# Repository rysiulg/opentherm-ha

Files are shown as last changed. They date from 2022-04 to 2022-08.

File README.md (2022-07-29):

Own implementation
Integration opemntherm co gas boiler to homeassistant
Covers in backgroung autodiscovery homeassistant mqtt climate controls also
CO Heat depends on NEWS temperature -it starts only if outside temp is below some value (default 2degC) -this temp is get from mqtt broker as averange NEWS temp.
Control is also available by www ;)
Default temp_NEWS have value 0 and default cutoff_NEWS is 2 so at defult heating is controlled, if from some reason communication is broke to mqqt to get new NEWS sensor than every temp_NEWS_interval_reduction_time_ms (default 30min) temp NEWS is reduced by 5% to finally get tempCutof value to enable heating.
Automode is control by room temp sensor and room temp target, heat mode is based on temperature CO pipe
In mqtt queue are double state value for dhw and double for boiler. eg. ch_state is centrah heat state with state reded from boiler, ch_state_software is software state which tells if we allow heat co. This is used for graphs -I use ch_state to make gradient on graph below Boiler temperature to see when boiler heated co, and flame status tells that boiler works.

Gets from mqtt broker
- temperature of NEWS (north, west south east averange temperature)
- state of working carbon heat co pump works -it disables hest to co

Built in similar interface like webserial, but on same websocket. autoscroll is on when slider is on bottom -in other case autoscroll in terminal is off ;) -it' is also possible to send some commands -i've done in 2 parts one is common for other modules ans other is for local project to be compatible with other projects ;)

Change to AsyncMQTT -by #define switch is possible to back to pubsync MQTT
added also #defined switch to be able on or off some module like arduino ota, influxdb etc.

ToDo:
Add histeresa to Boiler water and mayby for CO..
Add corrections to enable webupdate from bin file -but ota works well and stable for now ;)

Current UI on websockets:




for me it's working only local, remotelly over my VPN ;)

Old UI:


HomeAssistaNT:




Now updated version of http interface:

PLATFORM: Espressif 8266 (4.0.1) > WeMos D1 R2 and mini
HARDWARE: ESP8266 80MHz, 80KB RAM, 4MB Flash
PACKAGES:
 - framework-arduinoespressif8266 @ 3.30002.0 (3.0.2)
 - tool-esptool @ 1.413.0 (4.13)
 - tool-esptoolpy @ 1.30000.201119 (3.0.0)
 - tool-mklittlefs @ 1.203.210628 (2.3)
 - tool-mkspiffs @ 1.200.0 (2.0)
 - toolchain-xtensa @ 2.100300.210717 (10.3.0)
LDF: Library Dependency Finder -> https://bit.ly/configure-pio-ldf
LDF Modes: Finder ~ chain, Compatibility ~ soft
Found 43 compatible libraries
Scanning dependencies...
Dependency Graph
|-- ESPAsyncTCP-esphome @ 1.2.3
|-- ESPAsyncWebServer-esphome @ 2.1.0
|   |-- ESPAsyncTCP-esphome @ 1.2.3
|   |-- Hash @ 1.0
|   |-- ESP8266WiFi @ 1.0
|-- AsyncMqttClient-esphome @ 0.8.6
|   |-- ESPAsyncTCP-esphome @ 1.2.3
|-- ESP_DoubleResetDetector @ 1.3.1
|   |-- EEPROM @ 1.0
|   |-- LittleFS @ 0.1.0
|-- ESP8266 Influxdb @ 3.12.0
|   |-- ESP8266HTTPClient @ 1.2
|   |   |-- ESP8266WiFi @ 1.0
|   |-- ESP8266WiFi @ 1.0
|-- DallasTemperature @ 3.11.0
|   |-- OneWire @ 2.3.7
|-- OneWire @ 2.3.7
|-- OpenTherm Library @ 1.1.3
|-- ESP8266WiFi @ 1.0
|-- LittleFS @ 0.1.0
|-- ArduinoOTA @ 1.0
|   |-- ESP8266WiFi @ 1.0
|   |-- ESP8266mDNS @ 1.2
|   |   |-- ESP8266WiFi @ 1.0
|-- DNSServer @ 1.1.1
|   |-- ESP8266WiFi @ 1.0
|-- ESP8266HTTPClient @ 1.2
|   |-- ESP8266WiFi @ 1.0
|-- ESP8266mDNS @ 1.2
|   |-- ESP8266WiFi @ 1.0
|-- Hash @ 1.0
|-- Ticker @ 1.0
|-- EEPROM @ 1.0
Building in release mode
Compiling .pio\build\d1_mini\src\main.cpp.o
Linking .pio\build\d1_mini\firmware.elf
Retrieving maximum program size .pio\build\d1_mini\firmware.elf
Checking size .pio\build\d1_mini\firmware.elf
Advanced Memory Usage is available via "PlatformIO Home > Project Inspect"
RAM:   [=====     ]  54.7% (used 44840 bytes from 81920 bytes)
Flash: [======    ]  59.7% (used 623681 bytes from 1044464 bytes)

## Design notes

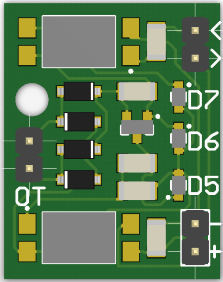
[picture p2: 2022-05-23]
PBA/opentherm_adapter_pcb.png

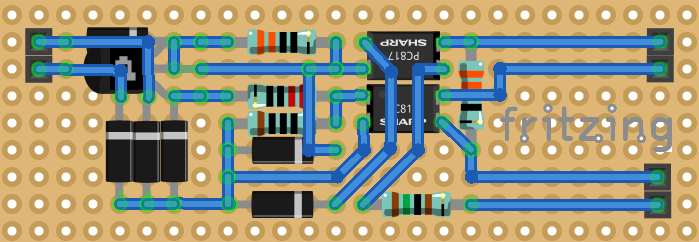
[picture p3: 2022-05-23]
PBA/arduino_opentherm_controller_circuit_board.png

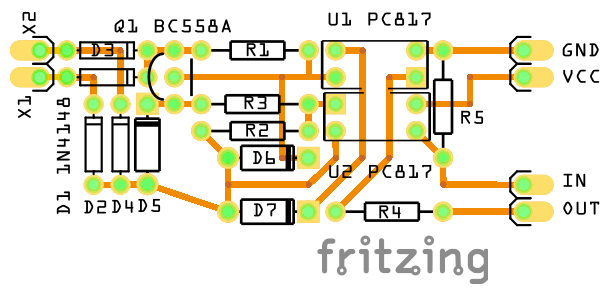
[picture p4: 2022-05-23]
PBA/arduino_opentherm_controller_PCB.png

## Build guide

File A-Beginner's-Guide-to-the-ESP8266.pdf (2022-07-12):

# A Beginner's Guide to the ESP8266

Pieter P, 08-03-2017

Some time ago, I wrote a Beginner's Guide to Arduino that seems to be very popular, so I decided to create a follow-up: A Beginner's Guide to the ESP8266. That's right, a tutorial on how to use the world's most popular $3 Wi-Fi board.

This is going to be a very in-depth tutorial, covering some networking concepts as well. If you're a beginner, and just want to go straight to the more exciting Wi-Fi part, feel free to do so, I included short TL;DR's in the longer, more technical parts.

A short overview of what I'll cover in this article:

1. What is an ESP8266? A short overview of what an ESP8266 is, and what you can do with it
2. Deciding on what board to buy: There's loads of different ESP8266 available these days, finding the one that's best for you can be hard
3. Installing the software: you need to install some software to program the ESP8266, and maybe a USB driver
4. Setting up the hardware: some modules and boards need some external components
5. The ESP8266 as a microcontroller: the ESP8266 can be used as a normal microcontroller, just like an Arduino
6. Network protocols: Before we start using the Wi-Fi capabilities of the ESP8266, I'll teach you some of the network protocols involved
7. Setting up a Wi-Fi connection: That's probably why you're reading this, right?
8. Name resolution: Find the ESP8266 on your local network using mDNS
9. Setting up a simple web server: This enables you to add web pages to the ESP8266, and browse them from your computer or phone
10. Setting up an advanced web server: a more advanced server with a real file system that allows you to upload new files over Wi-Fi
11. OTA - uploading programs over Wi-Fi: You don't have to upload programs over USB, you can use Wi-Fi instead
12. Wirelessly controlling your RGB lighting: Change the color of your LED strips using your phone or computer
13. Getting the time: Connect to a time server using NTP and sync the ESP's clock
14. Monitoring sensors: log the temperature in your living room, save it in flash memory and show it in a fancy graph in your browser
15. Getting email notifications: Turn on a notification light when you've got unread emails
16. Advanced features: use DNS, captive portals, Wi-Fi connector libraries, OSC ...

This guide expects some basic knowledge of microcontrollers like the Arduino. If that's something you're not already familiar with, I'd recommend you to read my Beginner's Guide to Arduino first, it covers a lot of the basics that I won't go into in this article.
I really want to focus on the ESP8266-specific things, like Wi-Fi and other network protocols, the ESP's hardware, software, IoT, etc ...

### What is an ESP8266?

The ESP8266 is a System on a Chip (SoC), manufactured by the Chinese company Espressif. It consists of a Tensilica L106 32-bit micro controller unit (MCU) and a Wi-Fi transceiver. It has 11 GPIO pins* (General Purpose Input/Output pins), and an analog input as well. This means that you can program it like any normal Arduino or other microcontroller. And on top of that, you get Wi-Fi communication, so you can use it to connect to your Wi-Fi network, connect to the Internet, host a web server with real web pages, let your smartphone connect to it, etc ... The possibilities are endless! It's no wonder that this chip has become the most popular IOT device available.

There are many different modules available, standalone modules like the ESP-## series by AI Thinker, or complete development boards like the NodeMCU DevKit or the WeMos D1. Different boards may have different pins broken out, have different Wi-Fi antennas, or a different amount of flash memory on board.

(*) The ESP8266 chip itself has 17 GPIO pins, but 6 of these pins (6-11) are used for communication with the on-board flash memory chip.

### Programming

There are different ways to program the ESP8266, but I'll only cover the method using the Arduino IDE. This is really easy for beginners, and it's a very familiar environment if you've used Arduino boards before.
Just keep in mind that it's not limited to this option: there's also an official SDK available to program it in real C, this is very useful if you want to optimize your code or do some advanced tricks that aren't supported by the Arduino IDE. Another possibility is to flash it with a LUA interpreter, so you can upload and run LUA scripts. Or maybe you're more familiar with Python? Then you should check out the MicroPython firmware to interpret MicroPython scripts. I'm sure there's other languages available as well, so just do a quick Google search and write your code in the language of your choice.

### Requirements

You'll need a couple of things in order to follow this guide:

An ESP8266 board
A computer that can run the Arduino IDE (Windows, Mac or Linux)
A USB-to-Serial converter, it is very important that you use a 3.3V model* A USB cable
A 3.3V power supply or voltage regulator*
A Wi-Fi network to connect to

(*) Your board may already include these. More information can be found in the next chapter.

## Hardware

### Deciding on what board to buy

ESP8266 is just the name of the chip, many companies have designed their own boards that use this chip, so there are many different ESP8266 boards on the market. If you don't know the difference between all these different models, you might have a hard time deciding on what board to buy.

The easiest (and fastest) way to get an ESP8266 board is to buy one from a well-known electronics shop like Adafruit or SparkFun, but if you want it cheap, you should check out Ebay or other sites where you can order them directly from China.

Development boards

Some boards have all kinds of features on-board to help developing ESP8266 hardware and software: for example, a USB to Serial converter for programming, a 3.3V regulator for power, on-board LEDs for debugging, a voltage divider to scale the analog input ...
If you're a beginner, I would definitely recommend a development board. It's easier to get started if you don't have to worry about all these things.

Bare-bones AI Thinker boards

If you want to add an ESP8266 to a small project, or if you want a cheaper* board, you might want to buy a board that doesn't have these features. In that case, you can buy one of the many ESP-## modules developed by AI Thinker. They contain just the ESP8266 and the necessary components to run it.
To program the board, you'll need an external USB-to-Serial converter. With some modules, you get an on-board antenna (PCB or ceramic) and an LED, some boards have just

an antenna connector, or no LEDs at all. They also differ in physical size, and flash memory size. An important thing to notice, is that some boards do not break out all GPIO pins. For example, the ESP-01 only has 2 I/O pins available (apart from the TX and RX pins), while other modules like the ESP-07 or ESP-12 break out all available I/O pins.

(*) The board itself is cheaper, but you'll have to spend more on external parts.

Overview

Here's a table with some of the most popular ESP8266 development boards and their features:

Board | GPIO

3.3V
Vreg

USB-to-Serial

Auto-Reset

Auto-Program

Flash | ADC
range Extra

SparkFun ESP8266
Thing
11 | + | - | + | ±*

512KB
(4Mb)

0-1V

Battery charger, crypto
element, temperature sensor, light sensor

SparkFun ESP8266
Thing - Dev Board
11 | + | + | + | +

512KB
(4Mb)

0-1V

Node MCU | 11 | + | + | + | + | 4MB (32Mb)

0-
3.3V

Adafruit Feather
HUZZAH with
ESP8266
11 | + | + | + | + | 4MB (32Mb) 0-1V | Battery charger

Adafruit HUZZAH
ESP8266 Breakout
11 | + | - | - | - | 4MB (32Mb) 0-1V | 5V-tolerant RX and Reset pins

ESP-##

4 -
11

512KB
(4Mb) –
4MB (32Mb)

0-1V Small and cheap

You can find the full list of ESP-## modules here.

As you can see, both the Node MCU and the Adafruit Feather HUZZAH are solid choices.

(*) When auto-program on the SparkFun ESP8266 Thing is enabled, you can't use the Serial Monitor.

### Getting the hardware ready

There are two main categories of ESP8266 boards: development boards with a USB interface (USB-to-Serial convertor) on-board, and boards without a USB connection.

Development boards with a USB interface

For example: NodeMCU, SparkFun ESP8266 Thing - Dev Board, SparkFun Blynk Board, Adafruit Feather HUZZAH with ESP8266 Wi-Fi ...

These boards will show up in Device manager (Windows) or in lsusb (Linux) as soon as you plug them in. They have a 3.3V regulator on-board, and can be programmed over USB directly, so you don't need any external components to get it working.
The only thing you may need to do, is solder on some headers.

Bare-bones boards and boards without a USB interface

This category has 2 sub-categories: boards with a 3.3V regulator on-board, and boards with just the ESP8266 and a flash memory chip, without 3.3V regulator. If your board doesn't have a 5V to 3.3V regulator, buy one separately. You could use an LM1117-3.3 for example. The on-board 3.3V regulator of most Arduino boards is not powerful enough to power the ESP.

To program the board, you'll need a USB-to-Serial converter. The FTDI FT232RL is quite popular, because it can switch between 5V and 3.3V. It is essential that the USB-to-Serial converter you buy operates at 3.3V. If you buy a 5V model, you will damage the ESP8266.

Connecting the USB-to-Serial converter

1. Connect the ground (GND) of the USB-to-Serial converter to the ground of the ESP8266.
2. Connect the RX-pin of the USB-to-Serial converter to the TXD pin of the ESP8266. (On some boards, it's labelled TX instead of TXD, but it's the same pin.)
3. Connect the TX-pin of the USB-to-Serial converter to the RXD pin of the ESP8266. (On some boards, it's labelled RX instead of RXD, but it's the same pin.)
4. If your ESP8266 board has a DTR pin, connect it to the DTR pin of the USB-to-Serial converter. This enables auto-reset when uploading a sketch, more on that later.

Enabling the chip

If you're using a bare-bone ESP-## board by AI Thinker, you have to add some resistors to turn on the ESP8266, and to select the right boot mode.

1. Enable the chip by connecting the CH_PD (Chip Power Down, sometimes labeled CH_EN or chip enable) pin to VCC through a 10KΩ resistor.
2. Disable SD-card boot by connecting GPIO15 to ground through a 10KΩ resistor.
3. Select normal boot mode by connecting GPIO0 to VCC through a 10KΩ resistor.
4. Prevent random resets by connecting the RST (reset) pin to VCC through a 10KΩ resistor.
5. Make sure you don't have anything connected to GPIO2 (more information in the next chapter).

Adding reset and program buttons

If your ESP8266 board doesn't have a reset button, you could add one by connecting a push button to between the RST pin and ground.

To put the chip into programming mode, you have to pull GPIO0 low during startup. That's why we also need a program button. Because it's possible to use GPIO0 as an output, we can't directly short it to ground, that could damage the chip. To prevent this, connect 470Ω resistor in series with the switch. It's important that this resistance is low enough, otherwise, it will be pulled high by the 10KΩ resistor we added in the previous paragraph.

Connecting the power supply

If the ESP8266 module you have doesn't have a 3.3V voltage regulator on board, you have to add one externally. You could use an LM1117-3.3 for example.

1. Connect the first pin of the regulator to ground.
2. Place a 10µF capacitor between pin 2 (Vout) and ground. Watch the polarity!
3. Place a 10µF capacitor between pin 3 (Vin) and ground.
4. Connect pin 2 to the 3.3V or VCCof the ESP8266.
5. Connect pin 3 to a 5V power source, a USB port, for example.

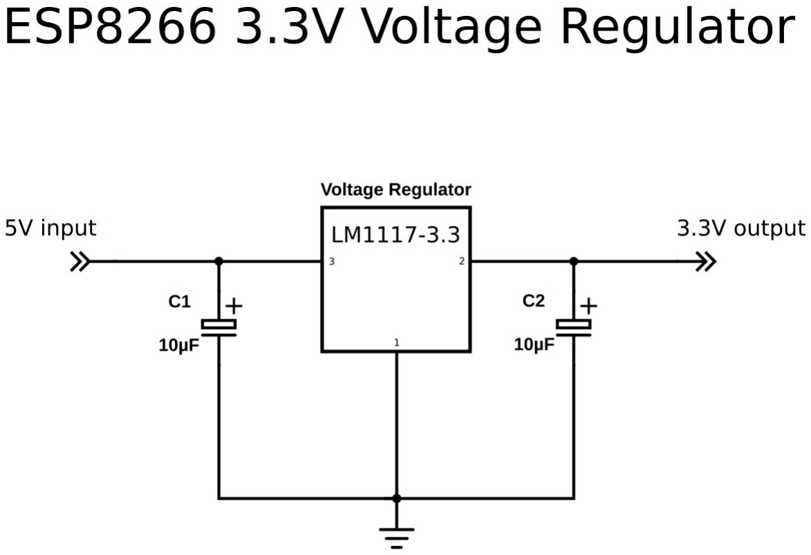
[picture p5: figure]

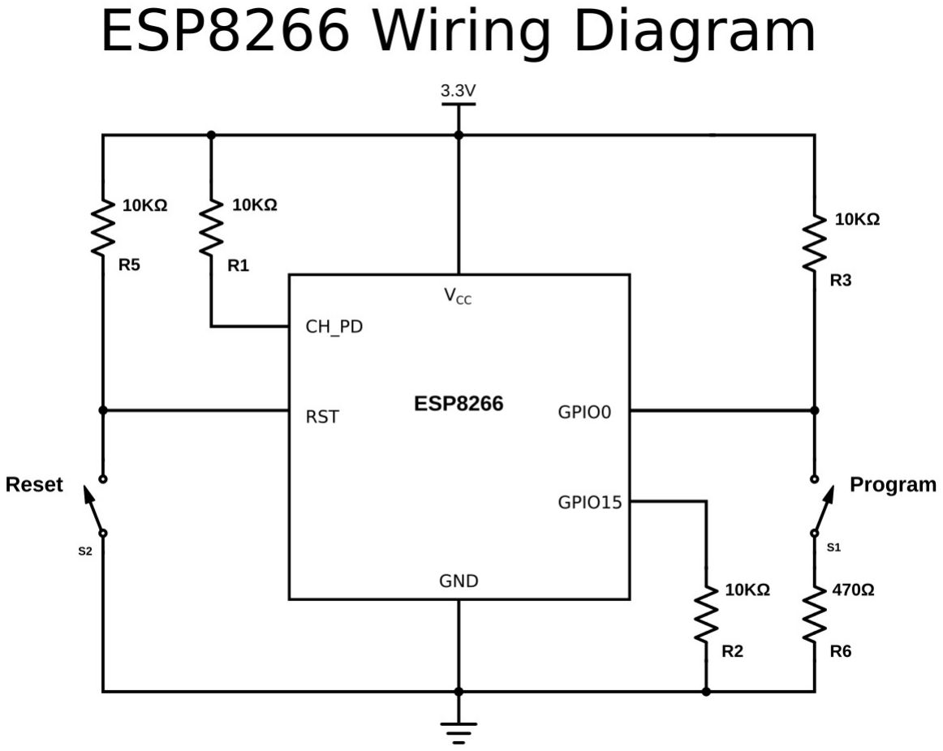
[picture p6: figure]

Before you begin ...

There's a few things you have to look out for when using an ESP8266: The most important thing is that it runs at 3.3V, so if you connect it to a 5V power supply, you'll kill it. Unlike some 3.3V Arduino or Teensy boards, the ESP8266's I/O pins are not 5V tolerant, so if you use a 5V USB-to-Serial converter, or 5V sensors etc. you'll blow it up.
A second thing to keep in mind is that the ESP8266 can only source or sink 12mA per output pin, compared to 20-40mA for most Arduinos.
The ESP8266 has one analog to digital converter, but it has a strange voltage range: 0 - 1V, voltages above 1V might damage the board.

One last thing to keep in mind is that the ESP8266 has to share the system resources and CPU time between your sketch and the Wi-Fi driver. Also, features like PWM, interrupts or I²C are emulated in software, most Arduinos on the other hand, have dedicated hardware parts for these tasks.
For most applications however, this is not too much of an issue.

## Software

### Installation of the required software

The first step is to download and install the Arduino IDE. I explained this in A Beginner's Guide to Arduino. (As of February 7th 2017, the latest stable version of the IDE is 1.8.1.)

To program the ESP8266, you'll need a plugin for the Arduino IDE, it can be downloaded from GitHub manually, but it is easier to just add the URL in the Arduino IDE:

1. Open the Arduino IDE.
2. Go to File > Preferences.
3. Paste the URL http://arduino.esp8266.com/stable/package_esp8266com_index.json into the Additional Board Manager URLs field.
(You can add multiple URLs, separating them with commas.)
4. Go to Tools > Board > Board Manager and search for 'esp8266'. Select the newest version, and click install. (As of February 7th 2017, the latest stable version is 2.3.0.)

You can check out the official install guide here.

Drivers

If you are using a board with the CH340(G) USB-to-Serial chip, like the NodeMCU, you'll probably have to install the USB drivers for it.
They can be found on GitHub.
If you are using a board with the CP2104 USB-to-Serial chip, like the Adafruit Feather HUZZAH board, you'll probably have to install USB drivers as well. You can find them on the Silicon Labs website. Boards with an FTDI chip should work right out of the box, without the need of installing any drivers.

### Python

If you want to use Over The Air updates on Windows, you have to install Python 2.7. You can download it from python.org. During the installation, you have to select the option to add Python to your path. If you don't do this, the Arduino IDE won't be able to find the Python executable.

### Examples

You can find all examples used in this article on my GitHub. Just download it as a .ZIP file, unzip it to a convenient location, and you're good to go!

## The ESP8266 as a microcontroller - Hardware

While the ESP8266 is often used as a ‘dumb’ Serial-to-WiFi bridge, it’s a very powerful microcontroller on its own. In this chapter, we’ll look at the non-Wi-Fi specific functions of the ESP8266.

### Digital I/O

Just like a normal Arduino, the ESP8266 has digital input/output pins (I/O or GPIO, General Purpose Input/Output pins). As the name implies, they can be used as digital inputs to read a digital voltage, or as digital outputs to output either 0V (sink current) or 3.3V (source current).

Voltage and current restrictions

The ESP8266 is a 3.3V microcontroller, so its I/O operates at 3.3V as well. The pins are not 5V tolerant, applying more than 3.6V on any pin will kill the chip.

The maximum current that can be drawn from a single GPIO pin is 12mA.

Usable pins

The ESP8266 has 17 GPIO pins (0-16), however, you can only use 11 of them, because 6 pins (GPIO 6 -
11) are used to connect the flash memory chip. This is the small 8-legged chip right next to the ESP8266. If you try to use one of these pins, you might crash your program.

GPIO 1 and 3 are used as TX and RX of the hardware Serial port (UART), so in most cases, you can’t use them as normal I/O while sending/receiving serial data.

Boot modes

As mentioned in the previous chapter, some I/O pins have a special function during boot: They select 1 of 3 boot modes:

GPIO15 | GPIO0 | GPIO2 | Mode
0V | 0V | 3.3V | Uart Bootloader
0V | 3.3V | 3.3V | Boot sketch (SPI flash)
3.3V | x | x | SDIO mode (not used for Arduino)

Note: you don’t have to add an external pull-up resistor to GPIO2, the internal one is enabled at boot.

We made sure that these conditions are met by adding external resistors in the previous chapter, or the board manufacturer of your board added them for you. This has some implications, however:

GPIO15 is always pulled low, so you can’t use the internal pull-up resistor. You have to keep this in mind when using GPIO15 as an input to read a switch or connect it to a device with an open-collector (or open-drain) output, like I²C.
GPIO0 is pulled high during normal operation, so you can’t use it as a Hi-Z input.
GPIO2 can’t be low at boot, so you can’t connect a switch to it.

Internal pull-up/-down resistors

GPIO 0-15 all have a built-in pull-up resistor, just like in an Arduino. GPIO16 has a built-in pull-down resistor.

PWM

Unlike most Atmel chips (Arduino), the ESP8266 doesn’t support hardware PWM, however, software PWM is supported on all digital pins. The default PWM range is 10-bits @ 1kHz, but this can be changed (up to >14-bit@1kHz).

### Analog input

The ESP8266 has a single analog input, with an input range of 0 - 1.0V. If you supply 3.3V, for example, you will damage the chip. Some boards like the NodeMCU have an on-board resistive voltage divider, to get an easier 0 - 3.3V range. You could also just use a trimpot as a voltage divider.

The ADC (analog to digital converter) has a resolution of 10 bits.

### Communication

Serial

The ESP8266 has two hardware UARTS (Serial ports):
UART0 on pins 1 and 3 (TX0 and RX0 resp.), and UART1 on pins 2 and 8 (TX1 and RX1 resp.), however, GPIO8 is used to connect the flash chip. This means that UART1 can only transmit data.

UART0 also has hardware flow control on pins 15 and 13 (RTS0 and CTS0 resp.). These two pins can also be used as alternative TX0 and RX0 pins.

I²C

The ESP doesn’t have a hardware TWI (Two Wire Interface), but it is implemented in software. This means that you can use pretty much any two digital pins. By default, the I²C library uses pin 4 as SDA and pin 5 as SCL. (The data sheet specifies GPIO2 as SDA and GPIO14 as SCL.) The maximum speed is approximately 450kHz.

SPI

The ESP8266 has one SPI connection available to the user, referred to as HSPI. It uses GPIO14 as CLK, 12 as MISO, 13 as MOSI and 15 as Slave Select (SS). It can be used in both Slave and Master mode (in software).

### GPIO overview

GPIO | Function | State | Restrictions
0 | Boot mode select | 3.3V | No Hi-Z
1 | TX0 | - | Not usable during Serial transmission
2 | Boot mode select TX1 | 3.3V (boot only) | Don’t connect to ground at boot time Sends debug data at boot time
3 | RX0 | - | Not usable during Serial transmission
4 | SDA (I²C) | - | -
5 | SCL (I²C) | - | -
6 - 11 | Flash connection | x | Not usable, and not broken out
12 | MISO (SPI) | - | -
13 | MOSI (SPI) | - | -
14 | SCK (SPI) | - | -
15 | SS (SPI) | 0V | Pull-up resistor not usable
16 | Wake up from sleep | - | No pull-up resistor, but pull-down instead Should be connected to RST to wake up

## The ESP8266 as a microcontroller - Software

Most of the microcontroller functionality of the ESP uses exactly the same syntax as a normal Arduino, making it really easy to get started.

### Digital I/O

Just like with a regular Arduino, you can set the function of a pin using pinMode(pin, mode); where pin is the GPIO number*, and mode can be either INPUT, which is the default, OUTPUT, or INPUT_PULLUP to enable the built-in pull-up resistors for GPIO 0-15. To enable the pull-down resistor for GPIO16, you have to use
INPUT_PULLDOWN_16.

(*) NodeMCU uses a different pin mapping, read more here. To address a NodeMCU pin, e.g. pin 5, use
D5: for instance: pinMode(D5, OUTPUT);

To set an output pin high (3.3V) or low (0V), use digitalWrite(pin, value); where pin is the digital pin, and value either 1 or 0 (or HIGH and LOW).

To read an input, use digitalRead(pin);

To enable PWM on a certain pin, use analogWrite(pin, value); where pin is the digital pin, and value a number between 0 and 1023.

You can change the range (bit depth) of the PWM output by using analogWriteRange(new_range);

The frequency can be changed by using analogWriteFreq(new_frequency);. new_frequency should be between 100 and 1000Hz.

### Analog input

Just like on an Arduino, you can use analogRead(A0) to get the analog voltage on the analog input. (0 = 0V, 1023 = 1.0V).

The ESP can also use the ADC to measure the supply voltage (VCC). To do this, include ADC_MODE(ADC_VCC); at the top of your sketch, and use ESP.getVcc(); to actually get the voltage.
If you use it to read the supply voltage, you can’t connect anything else to the analog pin.

### Communication

Serial communication

To use UART0 (TX = GPIO1, RX = GPIO3), you can use the Serial object, just like on an Arduino:
Serial.begin(baud).

To use the alternative pins (TX = GPIO15, RX = GPIO13), use Serial.swap() after Serial.begin.

To use UART1 (TX = GPIO2), use the Serial1 object.

All Arduino Stream functions, like read, write, print, println, ... are supported as well.

I²C and SPI

You can just use the default Arduino library syntax, like you normally would.

### Sharing CPU time with the RF part

One thing to keep in mind while writing programs for the ESP8266 is that your sketch has to share resources (CPU time and memory) with the Wi-Fi- and TCP-stacks (the software that runs in the background and handles all Wi-Fi and IP connections).
If your code takes too long to execute, and don’t let the TCP stacks do their thing, it might crash, or you could lose data. It’s best to keep the execution time of you loop under a couple of hundreds of milliseconds.

Every time the main loop is repeated, your sketch yields to the Wi-Fi and TCP to handle all Wi-Fi and TCP requests.

If your loop takes longer than this, you will have to explicitly give CPU time to the Wi-Fi/TCP stacks, by using including delay(0); or yield();. If you don’t, network communication won’t work as expected, and if it’s longer than 3 seconds, the soft WDT (Watch Dog Timer) will reset the ESP. If the soft WDT is disabled, after a little over 8 seconds, the hardware WDT will reset the chip.

From a microcontroller’s perspective however, 3 seconds is a very long time (240 million clockcycles), so unless you do some extremely heavy number crunching, or sending extremely long strings over Serial, you won’t be affected by this. Just keep in mind that you add the yield(); inside your for or while loops that could take longer than, say 100ms.

### Sources

This is where I got most of my information to writ this article, there’s some more details on the GitHub pages, if you’re into some more advanced stuff, like EEPROM or deep sleep etc.

https://github.com/esp8266/Arduino/issues/2942https://github.com/esp8266/Arduino/pull/2533/fileshttps://github.com/esp8266/Arduino/blob/master/doc/libraries.mdhttps: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

## Wi-Fi

Using the ESP8266 as a simple microcontroller is great, but the reason why most people use it, is its Wi-Fi capabilities. In this chapter, we'll dive into the wonderful world of network protocols, like Wi-Fi, TCP, UDP, HTTP, DNS ... All these acronyms might intimidate you, but I'll try my best to explain them step-by-step and in an easy way.

Some paragraphs are in italic. These provide some extra information, but are not critical to understanding the ESP's Wi-Fi functions, so don't get frustrated if there are things you don't understand.

It's really hard to give a clear explanation, without over-complicating things and while keeping it short enough as well. If you've got any feedback or remarks, be sure to leave a comment to help improve this article. Thanks!

### The TCP/IP stack

The system most people refer to as 'The Internet' isn't just one protocol: it's an entire stack of layers of protocols, often referred to as the TCP/IP stack. We'll go over these different layers, because we need to understand how our ESP8266 communicates with other devices on the network.

Layer | Protocols
Application | HTTP, FTP, mDNS, WebSocket, OSC ...
Transport | TCP, UDP
Internet | IP
Link | Ethernet, Wi-Fi ...

### The Link layer

The link layer contains the physical link between two devices, an Ethernet cable, for example, or a Wi-Fi connection. This is the layer that is closest to the hardware.
To connect an ESP8266 to the network, you have to create a Wi-Fi link. This can happen in two different ways:
1. The ESP8266 connects to a wireless access point (WAP or simply AP). The AP can be built-in to your modem or router, for example.
In this configuration, the ESP acts like a wireless station.
2. The ESP8266 acts as an access point and wireless stations can connect to it. These stations could be your laptop, a smartphone, or even another ESP in station mode.

Once the Wi-Fi link is established, the ESP8266 is part of a local area network (LAN). All devices on a LAN can communicate with each other.
Most of the time, the AP is connected to a physical Ethernet network as well, this means that the ESP8266 can also communicate with devices that are connected to the AP (modem/router) via a wired Ethernet connection (desktop computers, gaming consoles and set-top boxes, for instance).
If the ESP8266 is in access point mode, it can communicate with any station that is connected to it, and two stations (e.g. a laptop and a smartphone) can also communicate with each other.

The ESP can be used in AP-only, station-only, or AP+station mode.

TL;DR

The link layer is the physical link between devices: in the case of the ESP8266, this is a WiFi connection. The ESP can act as a station and connect to an access point, or act as an access point and let other devices connect to it.

### The Internet or Network layer

Although the devices are now physically connected (either through actual wires (Ethernet) or through radio waves (Wi-Fi)), they can't actually talk to each other yet, because they have no way of knowing where to send the message to.
That's where the Internet Protocol (IP) comes in. Every device on the network has a personal IP address. The DHCP server (Dynamic Host Configuration Protocol Server) makes sure that these addresses are unique.

This means that you can now send a message to a specific address.

There are two versions of the Internet Protocol: IPv4 and IPv6. IPv6 is an improved version of IPv4 and has much more addresses than IPv4 (because there are much more devices than available IPv4 addresses). In this article, we'll only talk about IPv4 addresses, since most LANs still use them.

The IP address consists of 4 numbers, for example 192.168.1.5 is a valid IPv4 address. It actually consists of two parts: the first part is 192.168.1, this is the address of the local network. The last digit, 5 in this case, is specific to the device.

By using IP addresses, we can find the ESP8266 on the network, and send messages to it. The ESP can also find our computer or our phone, if it knows their respective IP addresses.

Sub-net mask (optional)

This subdivision of the IP address is determined by the sub-net mask, often written as 255.255.255.0. You can see that it consists of four numbers, just like the IP address. If a part of the sub-net mask is 255, it means that the corresponding part of the IP address is part of the network address, if it's 0, the corresponding IP part is part of the address of the specific address. A different notation to "IP: 192.168.1.5, sub-net mask: 255.255.255.0" would be "192.168.1.5/24", because the binary representation of the sub-net mask is 11111111.11111111.11111111.00000000, and it has 24 ones. If you want to know more about sub-nets, I'd recommend you to read the Wikipedia article.
(A quick tip to help you remember: it's called the sub-net mask, because if you perform a bitwise AND operation on the IP address and the sub-net mask (i.e. use the sub-net mask as a mask for the IP address), you get the address of the sub-net.)

MAC addresses and ARP (optional)

It is actually impossible to send packets directly to another machine using only the IP address. To send a packet to a specific device on the LAN (Wi-Fi or Ethernet), you have to know its MAC-address. The MAC address is a unique number that is unique for every network device, and it never changes, it's hardwired in the network chip. This means that every ESP8266, every network card, every smartphone ... ever made, has a different MAC address.
So before the ESP can send a packet to your smartphone for example, it has to know its MAC address. It doesn't know this yet, the ESP only knows the IP address of the smartphone, say 192.168.1.6. To do this, the ESP sends a broadcast message (i.e. a message addressed to all devices on the LAN) saying "I'm looking for the MAC address of the device with the IP address 192.168.1.6". The ESP also includes its own IP and MAC address with the message. When the smartphone receives this broadcast message, it recognizes its own IP address, and responds to the ESP by sending its own MAC address. Now the ESP and the phone both know each other's IP and MAC addresses, and they can communicate using IP addresses. This method is called the Addres Resolution Protocol, or ARP.

What about the Internet?

As you might have noticed, I only talked about the local area network, these are the computers in your own house. So how can the ESP8266 communicate with the Internet, you may ask? Well, there's a lot of network infrastructure involved in 'The Internet', and they all obey the IP rules, to make sure most of your packets arrive at there destination. It's not that simple of course, there's a lot of things going on, like routing and Network Address Translation (NAT), but that falls outside the scope of this article, and it's not really something most people have to worry about.

TL;DR

The Internet layer uses IP addresses in order to know where it should send the data. This means that two devices can now send packets of data to each other, even over the Internet.

### The Transport layer

The different devices in the network do their best to deliver these IP packets to the addressee, however, it's not uncommon for a packet to get lost, so it will never arrive. Or the packet might get corrupted on the way: the data is no longer correct. IP also can't guarantee that the packets arrive in the same order they were sent in.
This means that we can't reliably send messages yet by only using the link and the Internet layer, since we can never know when and whether a packet will arrive, or know for certain that a received packet is correct.

We need a third layer on top of the Internet layer: the Transport layer.

There are mainly two protocols that make up this third layer: the Transmission Control Protocol (TCP) and the User Datagram Protocol (UDP).

TCP makes sure that all packets are received, that the packets are in order, and that corrupted packets are re-sent. This means that it can be used for communication between multiple applications, without having to worry about data integrity or packet loss. This is why it's used for things like downloading webpages, sending email, uploading files etc.
UDP on the other hand, doesn't guarantee that every packet reaches its destination, it does check for errors however, but when it finds one, it just destroys the packet, without re-sending it. This means that it's not as reliable as TCP, but it's faster, and has a much lower latency, because it doesn't require an open connection to send messages, like TCP does. That's why it's used in voice and video chats, and for example in online games.

If you want to know more about the differences between TCP and UDP, check out this video.

TL;DR

The IP protocol is not reliable, and has no error checking. TCP solves this by re-sending lost or corrupt packages, and orders packets that are received in the wrong order. UDP also checks for corrupt packages, but doesn't re-send them, so it has less latency than TCP.

### The Application layer

We now have reliable communication using TCP, but there's still one problem. Think of it this way: you are sending a letter, and TCP guarantees that it will arrive at its destination, but if the receiver doesn't understand the language it's written in, he won't know what to do with it.
In other words, we need a fourth layer of protocols, for two programs to be able to communicate with each other.
There's lots of different protocols out there, but we'll mostly focus on the protocols for web servers and browsers.

HyperText Transfer Protocol

The HyperText Transfer Protocol, or HTTP, is the protocol (cfr. language) that is used by both web servers and web clients in order to communicate. It uses text to perform send requests and responses from the client to the server and back again.
For example, when you type http://www.google.com into the address bar of a web browser (client), it will send an HTTP GET request to the Google web server. The server understands this HTTP request, and will send the Google webpage as a response. Or when you upload an image to Instagram, your browser sends an HTTP POST request with your selfie attached to the Instagram server. The server understands the request, saves the image and adds it into the database, sends the URL of the new image back to your browser, and the browser will add the image on the webpage.
As you can see, neither the client nor the server has to worry about the integrity of the messages they send, and they know that the recipient understands their language, and that it will know what to do with a certain HTTP request.
Most modern sites use a secure version of HTTP, called HTTPS. This secure connection encrypts the data, for security reasons. (You don't want anyone reading the packets from your mail server, or the packets you sent to your bank, for instance.)

WebSocket

HTTP is great for things like downloading webpages, uploading photos etc. but it's quite slow: every time you send an HTTP request, you have to start a new TCP connection to the server, then send your request, wait for the server to respond, and download the response. Wouldn't it be great if we didn't have to open a new connection every time we want to send some data, and if we could send and receive data at the same time at any moment we'd like? That's where WebSocket comes to the rescue: you can keep the TCP connection with the server open at all times, you get perfect TCP reliability, and it's pretty fast.

Open Sound Control

HTTP and WebSocket both use TCP connections. What if you want lower latency? Well, Open Sound Control, or OSC, uses UDP to send small pieces of data, like ints, floats, short text etc ... with very low latency. It was originally designed for controlling low latency audio applications, but it's a very flexible protocol, so it's often used for low-latency tasks other than audio control.

Domain Name System

As mentioned before, you can only send a message to another computer if you know its IP address. But when you browse the Internet, you only know a website's domain name (e.g. www.google.com). Your computer uses the Domain Name System to translate this domain name to the right IP address. More on this later.

### Sources

https://en.wikipedia.org/wiki/Internet_protocol_suitehttps://en.wikipedia.org/wiki/Port_(computer_networking) https://en.wikipedia.org/wiki/Transmission_Control_Protocolhttps://en.wikipedia.org/wiki/Internet_Protocolhttps://en.wikipedia.org/wiki/User_Datagram_Protocol

## Uploading sketches to the ESP8266

The upload procedure for ESP8266 boards is a little different from the normal Arduino procedure. Most Arduinos will automatically reset when a new program is being uploaded, and will automatically enter programming mode.
On some ESP boards you have to manually enter programming mode, and on the bare-bones modules, you even have to reset them manually.
However, there are some simple circuits you can use to get automatic uploads.

### Auto-reset

This only applies to boards without an on-board USB-to-Serial converter.

If the USB-to-Serial converter you're using has a DTR flow control line, you can automate the reset signal. When sending data to the ESP, the DTR line goes low, and stays low for some time. To reset the ESP, we need a low pulse on the RST pin. The problem is that the DTR pin stays low. To solve this, we're going to build a crude edge detector circuit, using a capacitor. Take a look at the following schematic:

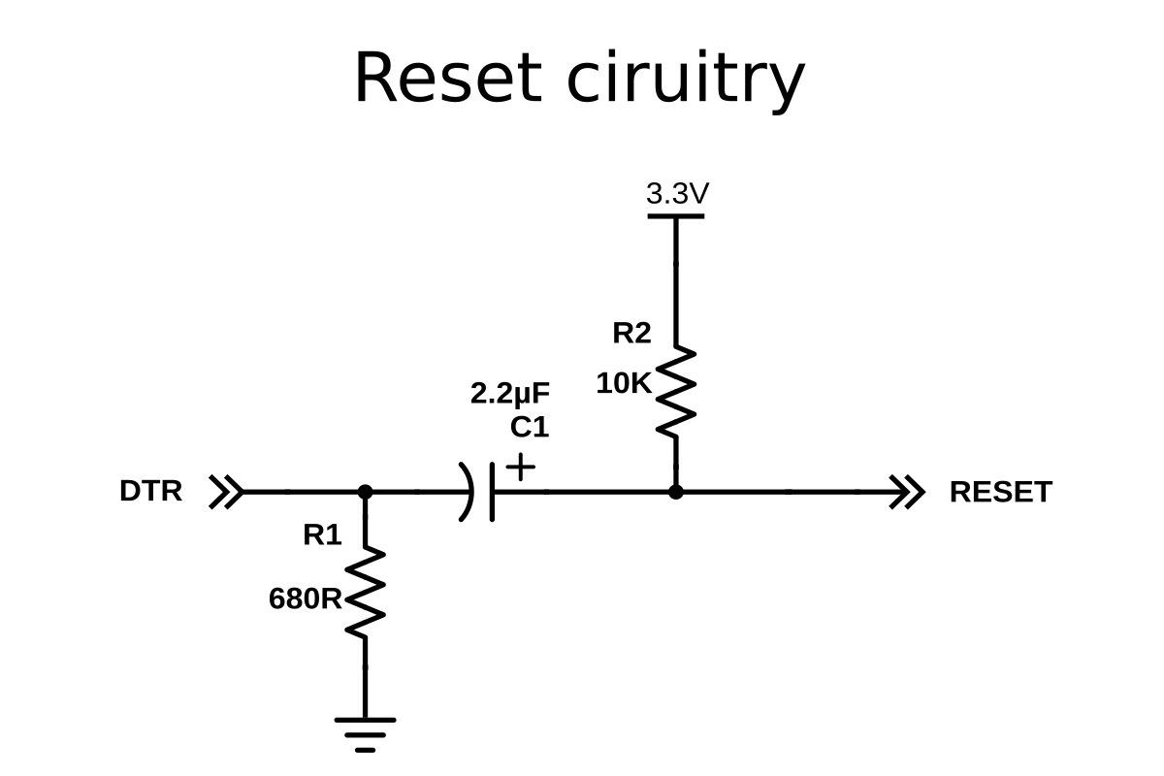
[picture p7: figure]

You might recognize that this is basically a low-cut filter. In normal conditions, DTR is high (3.3V), and the reset line is also high, because of the pull-up resistor R2. This means that the voltage across the capacitor is 0V. When DTR suddenly drops (to 0V), the voltage across the capacitor is still 0V, meaning that the reset line will be at 0V + 0V = 0V, and a reset is triggered.

However, C1 immediately starts charging through R2, and reaches 3.3V. At this point, DTR is still at 0V, meaning that there's now 3.3V across the capacitor. When DTR rises again, the reset line will be at 3.3V

+ 3.3V = 6.6V, and then immediately starts to discharge through R2, finally reaching 3.3V again, with 0V across C1.
This is a problem: 6.6V can damage the ESP, so we have to find a way to get rid of the positive peak.

One glance at this MATLAB simulation shows us the problem even better:

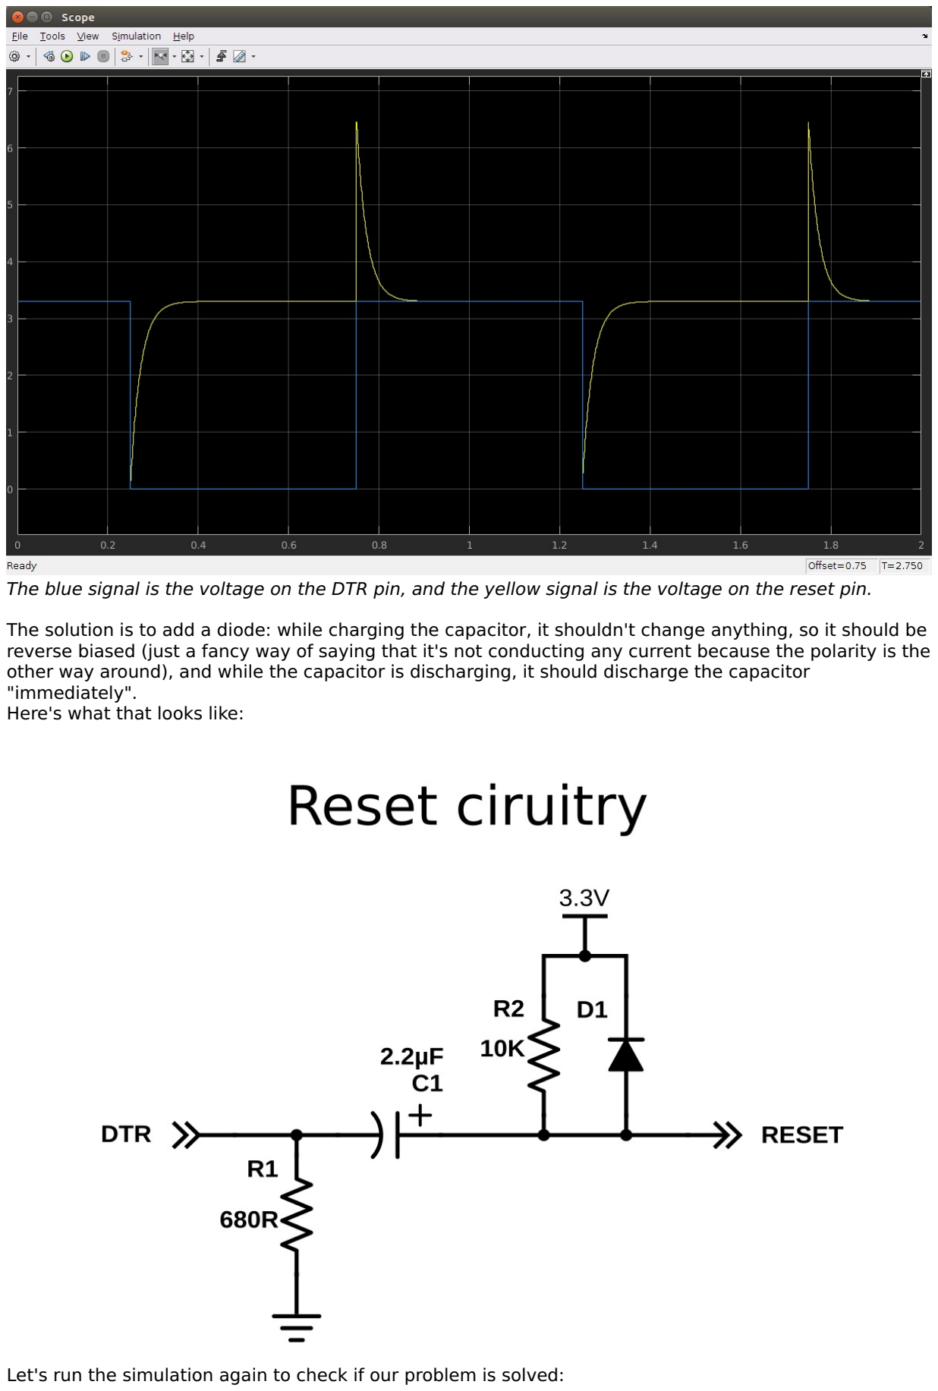
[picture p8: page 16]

The blue signal is the voltage on the DTR pin, and the yellow signal is the voltage on the reset pin.

The solution is to add a diode: while charging the capacitor, it shouldn't change anything, so it should be reverse biased (just a fancy way of saying that it's not conducting any current because the polarity is the other way around), and while the capacitor is discharging, it should discharge the capacitor "immediately".
Here's what that looks like:

Let's run the simulation again to check if our problem is solved:

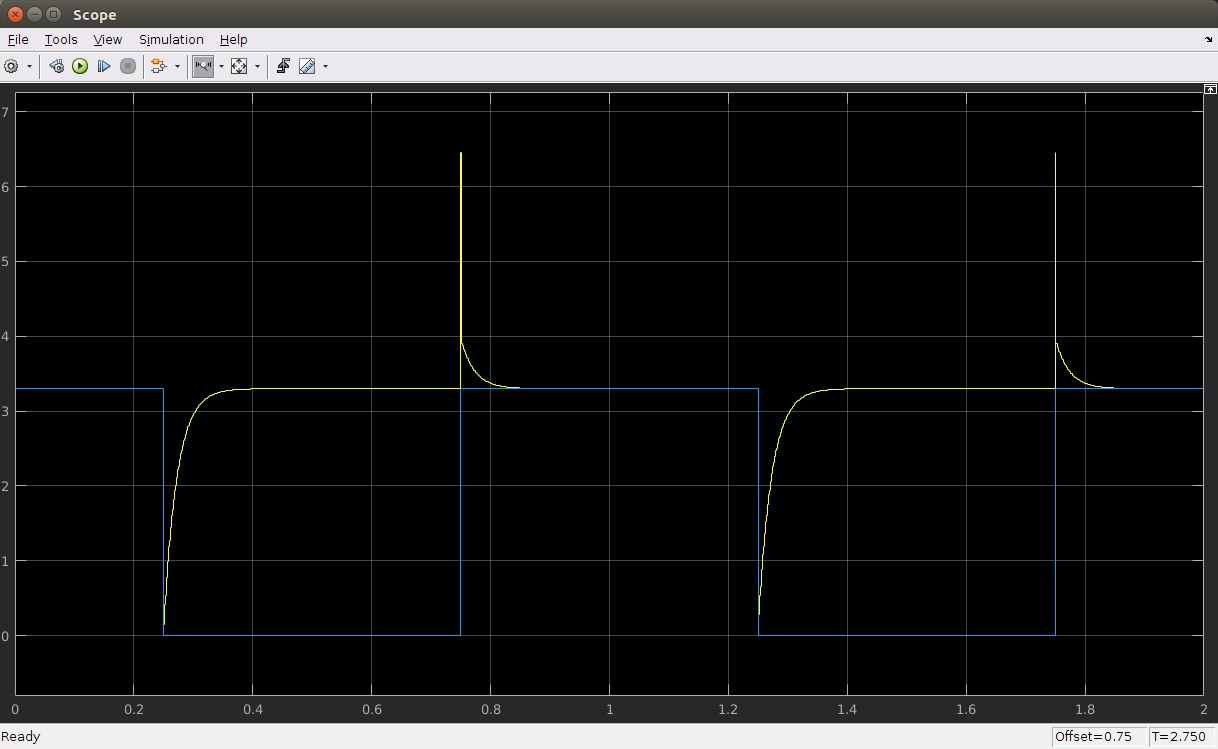
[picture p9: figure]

As you can see, the 6.6V peak is now very narrow, just like we wanted. It's impossible to discharge the capacitor instantly, that would require a capacitor and a diode with 0Ω of series resistance, and an infinite current, which is impossible, obviously. There's also a smaller but relatively wide peak of approximately 3.9V. This is because a diode only conducts when the voltage across it is higher than ~600mV. This means that the last 0.6V that's left in the capacitor (from 3.9 to 3.3V) will still be discharged through R2 only.
Nevertheless, the voltage peak is much lower and narrower than without the diode, and it's safe to connect to the ESP8266.

This exact circuit is also used in the Arduino Uno, for example.

Note: if you followed the instructions in the hardware step correctly, you should already have added R2 to your ESP.

How to use Auto-reset

To use this auto-reset circuit, connect it to the DTR line of your USB-to-Serial converter, and to the reset line of the ESP, as shown in the diagram. Then click compile (just because the first compilation can take quite some time). Go to Tools > Reset and select 'ck'. When it's done compiling, hold down the program button we added in the hardware step, and click upload. Wait for it to say "Uploading..." and then release the program button.

### Auto-reset and Auto-program

This only applies to boards without an on-board USB-to-Serial converter.

The method above still requires you to press a button to upload a new sketch. If your USB-to-Serial converter has a RTS line as well as a DTR line, you can automate the entire process.

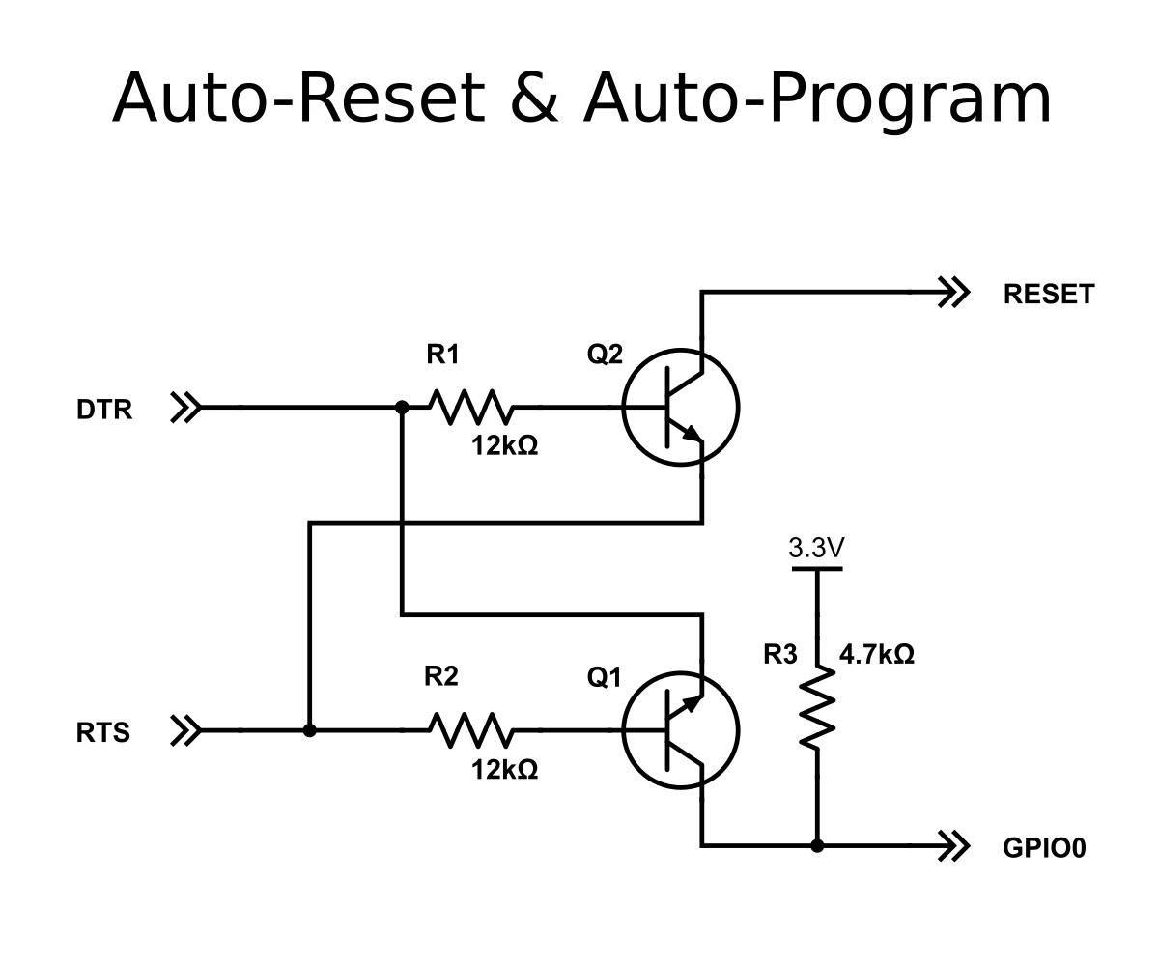
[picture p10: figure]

You may find out that the 4.7kΩ resistor doesn't work for you. In that case, try some other value, like 10kΩ, for example.

This method was first used in the NodeMCU, so go to Tools > Reset Method, and select "nodemcu". This will drive the DTR&RTS pins high and low in the right sequence to get it in programming mode before uploading.

This is by far the best method, but the problem is that you need access to both the RTS and DTR pins, while most USB-to-Serial adapters break out only one of the two.

### Manual reset and manual program

This only applies to boards without an on-board USB-to-Serial converter.

If you don't have a USB-to-Serial converter with DTR and RTS lines, you could also just use the reset and program buttons we added in the hardware chapter. To get the ESP in program mode, GPIO0 must be low while booting:

1. press and hold the reset button
2. press and hold the program button
3. release the reset button, the ESP will boot in program mode
4. release the program button
5. upload the sketch

If you want to get out of program mode without uploading, just press reset (without pressing the program button).

### Board options

If your specific board is in the Tools > Board list (e.g. NodeMCU, SparkFun and Adafruit boards), you can just select it, and you will get the right settings. When your board isn't in the list, you'll have to select a Generic ESP8266. In that case there's lots of new options in the Tools menu of the Arduino IDE, so let's go over them and pick the right settings.

Flash Mode

Like I said before, the ESP8266 uses an external flash chip for storage. You can communicate with this chip over 2 datalines (DIO), or over all 4 datalines (QIO). Using 4 lines is two times faster than 2 lines, so in most cases, you should choose QIO. (If you're doing some advanced stuff and you need 2 more GPIO pins, you could use 2 lines instead of 4, and use the 2 lines as I/O. Most modules don't give you access to these pins, though. )

Flash Size

Different boards/modules have different sizes of flash chips on board. There are boards with 512kB, 1MB, 2MB and 4MB of flash. To know how much flash your board has, you can try the Examples > ESP8266 > CheckFlashConfig to see if your flash setting is correct, or you can check the specifications of your specific board online.
You can also select the SPIFFS (SPI Flash File System) size. The SPIFFS partition is a small file system to store files. If you're not using it, you can select the minimum. Later on in the article, we'll use SPIFFS, and I'll remind you to select a larger SPIFFS size, but for now, it doesn't really matter.

Debug port

There's a load of things going on when the ESP is running: Things like Wi-Fi connections, TCP connections, DNS lookups ... you name it. All these small tasks produce a whole lot of debug output to help you troubleshoot. However, in a normal situation, where your program is behaving as expected, you don't need all those debug messages to flood the Serial Monitor, so you can just turn them off by selecting 'Disabled'.
If you do wish to receive debug messages, you can select the port to send them to. (Serial on pins 1 and 3, or Serial1 on pin 2)

Debug level

This allows you to choose what kind of debug messages you want to show.

Reset Method

As mentioned in the paragraphs above, there are different methods for auto-reset and auto-program. If you're using the first method (using the edge detector), you should use 'ck', if you use the two-transistor circuit, select 'nodemcu'.

Flash Frequency

If you need some extra memory speed, you could change the flash frequency from 40MHz to 80MHz. This is the clock frequency of the SPI/SDIO link.

CPU Frequency

If you need some extra CPU performance, you can double the clock speed from 80MHz to 160MHz. It's actually an overclock, but I've never had any issues or instability.

Upload Speed

The baud rate for uploading to the ESP. The default is 115200 baud, but you can go higher (if you're changing your sketch a lot, it might be too slow). 921600 baud works most of the time, but you may get an error sometimes, if that's the case, switching back to 115200 will probably solve all problems.

## Establishing a Wi-Fi connection

Like I mentioned in the previous chapter, the ESP8266 can operate in three different modes: Wi-Fi station, Wi-Fi access point, and both at the same time. We'll start by looking at the configuration of a Wi-Fi station.

### Station mode

Connecting to one specific network

#include <ESP8266WiFi.h> | // Include the Wi-Fi library

const char* ssid | = "SSID"; | // The SSID (name) of the Wi-Fi network you want to connect to
const char* password = "PASSWORD"; | // The password of the Wi-Fi network

void setup() {
Serial.begin(115200); | // Start the Serial communication to send messages to the computer
delay(10);
Serial.println('\n');
WiFi.begin(ssid, password); | // Connect to the network
Serial.print("Connecting to ");
Serial.print(ssid); Serial.println(" ...");

int i = 0;
while (WiFi.status() != WL_CONNECTED) { // Wait for the Wi-Fi to connect delay(1000);
Serial.print(++i); Serial.print(' ');
}

Serial.println('\n');
Serial.println("Connection established!");
Serial.print("IP address:\t");
Serial.println(WiFi.localIP()); | // Send the IP address of the ESP8266 to the computer
}

void loop() { }

The code to connect to a wireless access point is relatively straightforward: enter the SSID and the password of the network you want to connect to, and call the WiFi.begin function. Then wait for the connection to complete, et voilà, your ESP8266 is now connected to your Local Area Network.

Don't believe me? I'll prove it to you: open the Serial monitor (CTRL+SHIFT+M) and upload the sketch. You should see something like this:

Connecting to SSID ...
1 2 3 4 5 6 ...

Connection established!
IP address: 192.168.1.3

Now go to your computer and open up a terminal: On Windows, search for "Command Prompt", on Mac or Linux, search for "Terminal". You could also use the shortcuts: on Windows, hit + R, type "cmd" and hit enter, on Linux, use CTRL+ALT+T .

Next, type ping , and then the IP address you received in the Serial monitor. If you're on Mac or Linux, use CTRL+C to stop it after a couple of lines. The output should look something like this:

user@computername:~$ ping 192.168.1.3
PING 192.168.1.3 (192.168.1.3) 56(84) bytes of data.
64 bytes from 192.168.1.3: icmp_seq=1 ttl=128 time=6.38 ms
64 bytes from 192.168.1.3: icmp_seq=2 ttl=128 time=45.2 ms 64 bytes from 192.168.1.3: icmp_seq=3 ttl=128 time=69.1 ms 64 bytes from 192.168.1.3: icmp_seq=4 ttl=128 time=94.0 ms 64 bytes from 192.168.1.3: icmp_seq=5 ttl=128 time=20.5 ms 64 bytes from 192.168.1.3: icmp_seq=6 ttl=128 time=7.37 ms
^C
--- 192.168.1.3 ping statistics ---
6 packets transmitted, 6 received, 0% packet loss, time 5003ms
rtt min/avg/max/mdev = 6.384/40.463/94.047/32.588 ms

The ping command sends small packets to the IP address of the ESP8266. When the ESP receives such a packet, it sends it back to the sender. Ping is part of the second layer of the TCP/IP stack, the Internet layer. It relies on both the Data Link layer (Wi-Fi) and the Internet Protocol*.
You can see that in the example above, we sent 6 packets to the ESP, and we also received 6 response (echo) packets. This tells us that the Data Link, the Wi-Fi connection, and the Internet Protocol are working correctly.

We now know that the ESP can successfully communicate with other devices on the network, and if your local network is online (if it is connected to the Internet via your modem), the ESP can also communicate with any device on the web !

Ping is a great tool to check if the ESP (or any device, really) is still connected to the network, and if it's still working fine.
One drawback is that IP addresses can change over time, but that's a problem we'll address in one of the following chapters ...

(*) I'm simplifying things a bit here. Actually, ping is part of the Internet Control Message Protocol (ICMP), that's also part of the second layer, just like the Internet Protocol. Don't worry too much about it, just remember that if you can send ping packets to a device, you can also send IP packets.

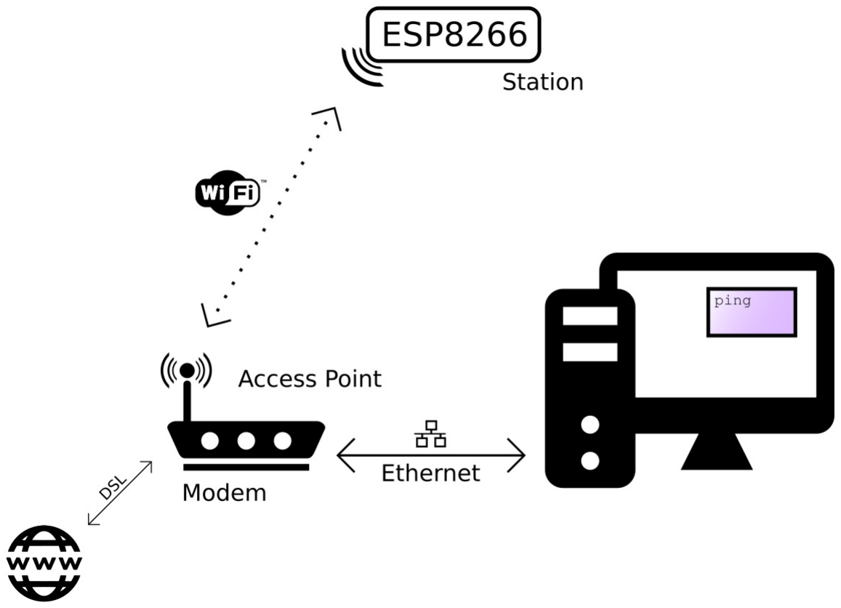
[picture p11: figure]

The device with the antenna serves many different purposes:

Access point: Other Wi-Fi devices can connect to it, to be part of the local network.
Router: It routes IP packets to the right sub-nets so that they will arrive at their destination. E.g. if the computer sends a message that is meant for the ESP over the Ethernet sub-net, the router will send the packet to the Wi-Fi sub-net, because it knows that's where the ESP is. Modem: if the router can't find the addressee on the local network, the packet will be passed on to

the integrated modem, and it will be sent to the Internet Service Provider over a DSL line, heading for the Internet, where lots of other routers will try to get the packet to the right destination.

But in reality, you don't have to worry too much about it, because it's all done for you, in a fraction of a second without you even noticing it!

Automatically connect to the strongest network

The sketch above might be enough for your specific application, but if you need to be able to connect to multiple Wi-Fi networks, for example the Wi-Fi at home and the Wi-Fi at the office, it won't work.
To solve this problem, we'll use the Wi-Fi-Multi library: You can add as many networks as you like, and it automatically connects to the one with the strongest signal.

#include <ESP8266WiFi.h> | // Include the Wi-Fi library

#include <ESP8266WiFiMulti.h> | // Include the Wi-Fi-Multi library

ESP8266WiFiMulti wifiMulti; | // Create an instance of the ESP8266WiFiMulti class, called 'wifiMulti'

void setup() {
Serial.begin(115200); | // Start the Serial communication to send messages to the computer
delay(10);
Serial.println('\n');

wifiMulti.addAP("ssid_from_AP_1", "your_password_for_AP_1"); // add Wi-Fi networks you want to connect to
wifiMulti.addAP("ssid_from_AP_2", "your_password_for_AP_2");
wifiMulti.addAP("ssid_from_AP_3", "your_password_for_AP_3");

Serial.println("Connecting ...");
int i = 0;
while (wifiMulti.run() != WL_CONNECTED) { // Wait for the Wi-Fi to connect: scan for Wi-Fi networks, and connect to the strongest of the networks above
delay(1000);
Serial.print('.');
}
Serial.println('\n');
Serial.print("Connected to ");
Serial.println(WiFi.SSID()); | // Tell us what network we're connected to
Serial.print("IP address:\t");
Serial.println(WiFi.localIP()); | // Send the IP address of the ESP8266 to the computer
}

void loop() { }

### Access Point mode

To configure the ESP8266 as an access point, to allow other devices like smartphones or laptops to connect to it, you can use the softAP function:

#include <ESP8266WiFi.h> | // Include the Wi-Fi library

const char *ssid = "ESP8266 Access Point"; // The name of the Wi-Fi network that will be created
const char *password = "thereisnospoon"; // The password required to connect to it, leave blank for an open network

void setup() {
Serial.begin(115200);
delay(10);
Serial.println('\n');
WiFi.softAP(ssid, password); | // Start the access point
Serial.print("Access Point \"");
Serial.print(ssid);
Serial.println("\" started");

Serial.print("IP address:\t");
Serial.println(WiFi.softAPIP()); | // Send the IP address of the ESP8266 to the computer
}

void loop() { }

To see if it works, open the Wi-Fi settings on your computer, look for a network called "ESP8266 Access Point", enter the password "thereisnospoon", and connect to it. Then open a terminal, and ping to 192.168.4.1 (this is the default IP address of our ESP AP). You'll see that the ESP responds to your pings.

However, if you try to go to an online website, you'll get a timeout or a DNS error. This is because the ESP itself is not connected to the internet. The sub-net that consists of the ESP and the computer is not connected to any other networks, so there's no way for a packet on this network to make it to the Internet.

If you connected a second station to the ESP access point on the other hand, you would be able to ping from one station to the other without problems, because they're on the same network.

## Multicast Domain Name System

### DNS

Let's face it, constantly typing IP addresses is really cumbersome, and it would be impossible to remember all your favorite websites' addresses, especially if they use IPv6.
That's why domain names were introduced: a simple string of text that's easy to remember, for example www.google.com.

However, to send a request to a website, your computer still needs to know its IP address. That's where DNS comes in. It stands for Domain Name System, and is a way to translate a website's domain name to its IP address. On the Internet, there are a lot of DNS servers. Each DNS server has a long list of domain names and their corresponding IP addresses. Devices can connect to a DNS server and send a domain name, the DNS server will then respond with the IP address of the requested site.
You could compare it to a telephone directory: you can look up a name to find the corresponding phone number.

The DNS lookup happens completely in the background: when you go to a website in your browser, it will first send a request to a DNS server (this implies that the computer knows the IP address of the DNS server itself), wait for the response of the lookup, and then send the actual request to the right IP address.

### mDNS

DNS works great for normal sites on the Internet, but most local networks don't have their own DNS server. This means that you can't reach local devices using a domain name, and you're stuck using IP addresses ...

Fortunately, there's another way: multicast DNS, or mDNS. mDNS uses domain names with the .local suffix, for example http://esp8266.local. If your computer

needs to send a request to a domain name that ends in .local, it will send a multicast query to all other devices on the LAN that support mDNS, asking the device with that specific domain name to identify itself. The device with the right name will then respond with another multicast and send its IP address. Now that your computer knows the IP address of the device, it can send normal requests.

Luckily for us, the ESP8266 Arduino Core supports mDNS:

#include <ESP8266WiFi.h> | // Include the Wi-Fi library

#include <ESP8266WiFiMulti.h> | // Include the Wi-Fi-Multi library

#include <ESP8266mDNS.h> | // Include the mDNS library

ESP8266WiFiMulti wifiMulti; | // Create an instance of the ESP8266WiFiMulti class, called 'wifiMulti'

void setup() {
Serial.begin(115200); | // Start the Serial communication to send messages to the computer
delay(10);
Serial.println('\n');

wifiMulti.addAP("ssid_from_AP_1", "your_password_for_AP_1"); // add Wi-Fi networks you want to connect to
wifiMulti.addAP("ssid_from_AP_2", "your_password_for_AP_2");
wifiMulti.addAP("ssid_from_AP_3", "your_password_for_AP_3");

Serial.println("Connecting ...");
int i = 0;
while (wifiMulti.run() != WL_CONNECTED) { // Wait for the Wi-Fi to connect: scan for Wi-Fi networks, and connect to the strongest of the networks above
delay(1000);
Serial.print(++i); Serial.print(' ');
}
Serial.println('\n');
Serial.print("Connected to ");
Serial.println(WiFi.SSID()); | // Tell us what network we're connected to
Serial.print("IP address:\t");
Serial.println(WiFi.localIP()); | // Send the IP address of the ESP8266 to the computer
if (!MDNS.begin("esp8266")) { | // Start the mDNS responder for esp8266.local
Serial.println("Error setting up MDNS responder!");
}
Serial.println("mDNS responder started");
}

void loop() { }

Upload it and open ping again. Try to ping to esp8266.local:

user@computername:~$ ping esp8266.local
PING esp8266.local (10.92.237.128) 56(84) bytes of data.
64 bytes from 10.92.237.128: icmp_seq=1 ttl=128 time=5.68 ms 64 bytes from 10.92.237.128: icmp_seq=2 ttl=128 time=3.41 ms 64 bytes from 10.92.237.128: icmp_seq=3 ttl=128 time=2.55 ms 64 bytes from 10.92.237.128: icmp_seq=4 ttl=128 time=2.19 ms 64 bytes from 10.92.237.128: icmp_seq=5 ttl=128 time=2.29 ms 64 bytes from 10.92.237.128: icmp_seq=6 ttl=128 time=2.74 ms ^C
--- esp8266.local ping statistics ---
6 packets transmitted, 6 received, 0% packet loss, time 5007ms
rtt min/avg/max/mdev = 2.190/3.148/5.687/1.202 ms

As you can see, ping will automatically find the IP address of the ESP for you.

mDNS is supported on Windows, OSX, Linux and iOS, but not (yet?) on Android.
It's a real shame that Android doesn't support it, you can help by starring this issue report for the Chromium project to ask for mDNS support in Chrome on Android.

Of course, you can change the domain name of the ESP by changing the parameter of MDNS.begin.

## ESP8266 Web Server

Being able to ping the ESP is quite an achievement if you look at it from a technical point of view, but for most people, it's not that exciting, and not really useful.
In this chapter, I'll cover the basics of a web server, and teach you how to host a web page on the ESP.

### Web servers

A web server is an Internet-connected device that stores and serves files. Clients can request such a file or another piece of data, and the server will then send the right data/files back to the client. Requests are made using HTTP.

### HTTP

HTTP or the Hypertext Transfer Protocol is the text-based protocol used to communicate with (web) servers. There are multiple HTTP request methods, but I'll only cover the two most widely used ones: GET and POST.

### HTTP GET

GET requests are used to retrieve data from a server, a web page for instance. It shouldn't change anything on the server, it just gets the data from the server, without side effects.

When you open a webpage in your browser, it will take the URL and put it in an HTTP GET request. This is just plain text. Then it will send the request to the right server using TCP. The server will read the request, check the URL, and send the right HTTP response for that URL back to the browser.

The anatomy of a GET request

The most important parts of a GET request are the request line and the host header. Let's take a look at an example:
If you click the following link: https://www.w3.org/Protocols/rfc2616/rfc2616-sec5.html, your browser will send out the following HTTP request:

GET /Protocols/rfc2616/rfc2616-sec5.html HTTP/1.1
Host: www.w3.org
Connection: keep-alive
Pragma: no-cache
Cache-Control: no-cache
Upgrade-Insecure-Requests: 1
User-Agent: Mozilla/5.0 (X11; Linux x86_64) AppleWebKit/537.36 (KHTML, like Gecko) Chrome/56.0.2924.87 Safari/537.36
Accept: text/html,application/xhtml+xml,application/xml;q=0.9,image/webp,*/*;q=0.8
DNT: 1
Referer: https://www.google.be/
Accept-Encoding: gzip, deflate, sdch, br
Accept-Language: en-US,en;q=0.8

The first line is the request line: it contains the request method: GET, in this case, the URI or Uniform Resource Identifier: /Protocols/rfc2616/rfc2616-sec5.html, and the HTTP version: 1.1.
The second line is the host header, it specifies the domain name of the host (server).
There are many other headers as well, but they're not really important when using an ESP8266.
Most servers will check if the URI is a file on their file system, and if that's the case, they'll send that file as a response.

Viewing HTTP headers in the browser

If you want to check the headers your browser sends, you can press F12, go to the network tab, reload the page, and click the request you want to inspect. If you want, you can click 'view source', this will show you the actual HTTP text.
Here's what that looks like in Chrome:

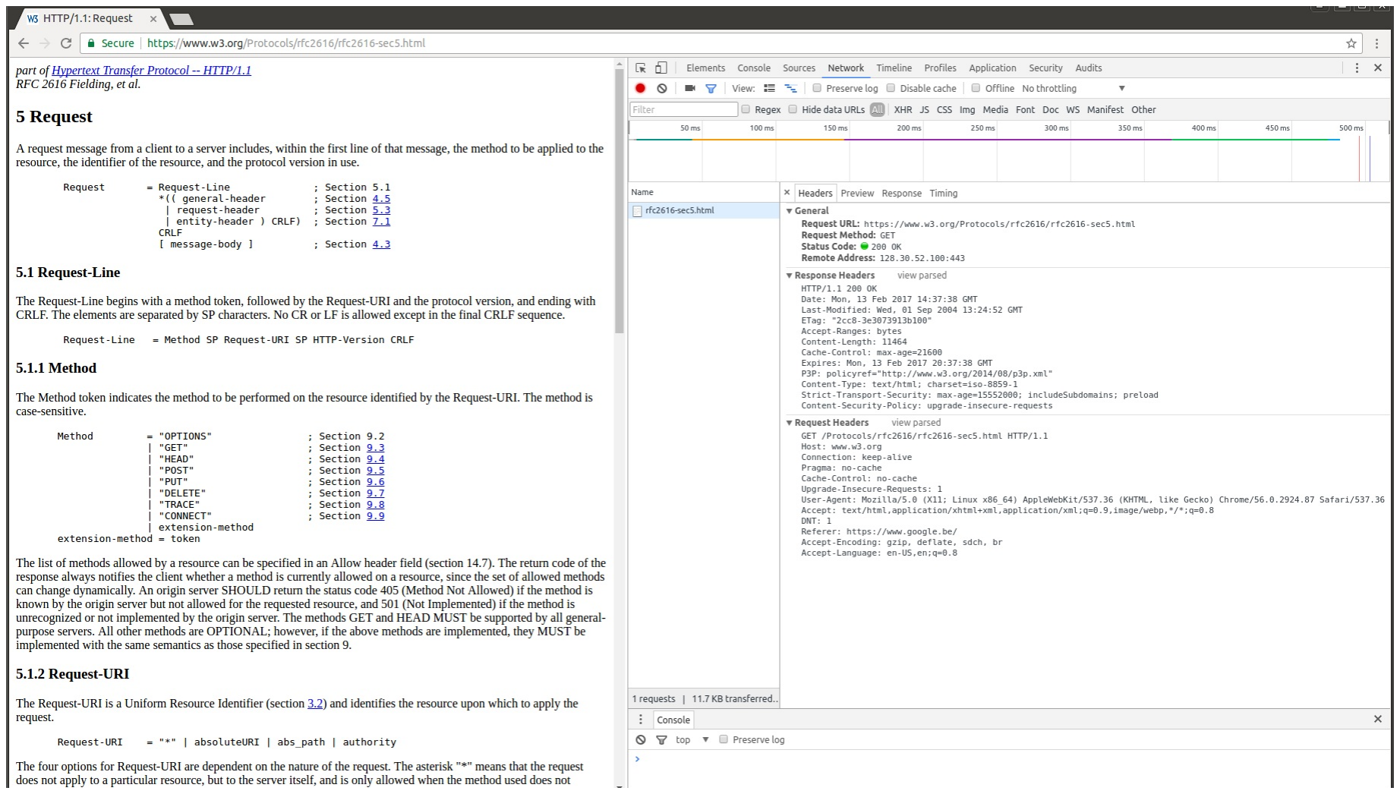
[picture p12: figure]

Sending extra information to the server

Sometimes, you might want to add extra information to the GET request. You can send key-value pairs by adding a question mark (?) to the URI, followed by key=value. Multiple pairs are separated by an ampersand (&).
For example:

GET /get-phone-number.php?firstName=John&lastName=Doe HTTP/1.1
Host: www.phonebook.example.com

If you use any special characters in the key or value names, you have to URL-encode them.

HTTP POST

POST requests are used to send data to the server, for example, to send your user name and password to the server when you log in, or when you upload a photo. Unlike GET, POST can change the data on the server or the state of the server.
POST has a body that can contain data that is sent to the server.

The anatomy of a POST request

For example, the login page of your favorite site might send something like this when you enter your credentials and click the login button:

POST /login.php HTTP/1.1
Host: www.example.com
Connection: keep-alive
Content-Length: 480
Origin: http://www.example.com
Content-Type: multipart/form-data; boundary=----WebKitFormBoundaryQNEJOasMvgAOg8Kt

As you can see, the request line now has the POST method in it, and is still followed by a URI, /login.php, and the HTTP version, 1.1. The host header still contains just the domain name.

The real difference is the request body: a GET request has no payload, while you can add a lot of data to the body of a POST request. This data could be normal key-value pairs, like a username and a password, or actual files that are being uploaded.
Also note the Content-Type header: it tells the server what kind of data can be found in the body of the POST request.

Let's take a look at the body of the login example:

------WebKitFormBoundaryQNEJOasMvgAOg8Kt

Content-Disposition: form-data; name="username"

John Doe
------WebKitFormBoundaryQNEJOasMvgAOg8Kt Content-Disposition: form-data; name="password"

p@ssw0rd123
------WebKitFormBoundaryQNEJOasMvgAOg8Kt Content-Disposition: form-data; name="token"

9i9ZoLHl5pkRAeuKCEu76TbaCnMphwYkPEovEUY9PHk=
------WebKitFormBoundaryQNEJOasMvgAOg8Kt--

As you can see, there are three parameters inside the body, every parameter has a name (e.g. username), and a value (e.g. John Doe).

You could also use the same syntax we used before when adding parameters to a GET request:

POST /add-user.php HTTP/1.1
Host: www.example.com
Content-Length: 27
Content-Type: application/x-www-form-urlencoded ...

And the payload:

firstName=John&lastName=Doe

As you can see, the Content-Typeheader is different, indicating that the encoding of the values in the payload is different.

### HTTP status codes

A server should answer all requests with an HTTP status code. This is a 3-digit number indicating if the request was successful or telling the client what went wrong. Here's a table with some of the most important and useful ones.
Status Code | Meaning
200 | OK: the request was successful
303 | See Other: used to redirect to a different URI, after a POST request, for instance
400 | Bad Request: the server couldn't understand the request, because the syntax was incorrect
401 | Unauthorized: user authentication is required
403 | Forbidden: the server refuses to execute the request, authorization won't help
404 | Not Found: the requested URI was not found
500 | Internal Server Error: The server encountered an unexpected condition and couldn't fulfill the request

### TCP & UDP Ports

In most cases, one device has many different services, for example, a web server, an email server, an FTP server, a Spotify streaming service, ...
If the device had just an IP address, it would be impossible to know which application a packet was sent to. That's why every service has a port number. It's an identifier for all different services or applications on a single device. In the example above, the web server will only listen for requests on port 80, the email server only on port 25, the FTP server only on port 20, Spotify will only receive streams on port 4371 ...
To specify a certain port, you can use a colon after the IP address of after the domain name. But most of the time, you don't have to add it explicitly. For example, all web servers listen on port 80, so a web browser will always connect to port 80.

http://stackoverflow.com/questions/176264/what-is-the-difference-between-a-uri-a-url-and-a-urnhttps://www.w3.org/Protocols/rfc2616/rfc2616-sec10.htmlhttps://en.wikip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

## ESP8266 First Web Server

The actual implementation of a web server is much easier than it sounds, because the ESP8266 Arduino Core includes some great libraries that handle pretty much everything for you. Let's look at a basic Hello World! example.

#include <ESP8266WiFi.h>

#include <WiFiClient.h>

#include <ESP8266WiFiMulti.h>

#include <ESP8266mDNS.h>

#include <ESP8266WebServer.h> | // Include the WebServer library

ESP8266WiFiMulti wifiMulti; | // Create an instance of the ESP8266WiFiMulti class, called 'wifiMulti'
ESP8266WebServer server(80); | // Create a webserver object that listens for HTTP request on port 80
void handleRoot(); | // function prototypes for HTTP handlers
void handleNotFound();

void setup(void){
Serial.begin(115200); | // Start the Serial communication to send messages to the computer
delay(10);
Serial.println('\n');

wifiMulti.addAP("ssid_from_AP_1", "your_password_for_AP_1"); // add Wi-Fi networks you want to connect to
wifiMulti.addAP("ssid_from_AP_2", "your_password_for_AP_2");
wifiMulti.addAP("ssid_from_AP_3", "your_password_for_AP_3");

Serial.println("Connecting ...");
int i = 0;
while (wifiMulti.run() != WL_CONNECTED) { // Wait for the Wi-Fi to connect: scan for Wi-Fi networks, and connect to the strongest of the networks above
delay(250);
Serial.print('.');
}
Serial.println('\n');
Serial.print("Connected to ");
Serial.println(WiFi.SSID()); | // Tell us what network we're connected to
Serial.print("IP address:\t");
Serial.println(WiFi.localIP()); | // Send the IP address of the ESP8266 to the computer
if (MDNS.begin("esp8266")) { | // Start the mDNS responder for esp8266.local
Serial.println("mDNS responder started");
} else {
Serial.println("Error setting up MDNS responder!");
}
server.on("/", handleRoot); | // Call the 'handleRoot' function when a client requests URI
"/"
server.onNotFound(handleNotFound); | // When a client requests an unknown URI (i.e. something
other than "/"), call function "handleNotFound"
server.begin(); | // Actually start the server
Serial.println("HTTP server started");
}

void loop(void){
server.handleClient(); | // Listen for HTTP requests from clients
}

void handleRoot() {
server.send(200, "text/plain", "Hello world!"); // Send HTTP status 200 (Ok) and send some text to the browser/client
}

void handleNotFound(){
server.send(404, "text/plain", "404: Not found"); // Send HTTP status 404 (Not Found) when there's no handler for the URI in the request
}

There's a lot of code that's the same as in the Wi-Fi and mDNS examples.
The actual server code is pretty straightforward. First, we create a server instance that listens for HTTP requests on port 80. This is the default port for web servers. In the setup, we tell the server what to do with certain HTTP requests. If the URI '/' is requested, the server should reply with a HTTP status code of 200 (Ok) and then send a response with the words 'Hello world!'. We put the code for generating a response in a separate function, and the we tell the server to execute it when '/' is requested, using the
server.on function.

We haven't specified what the server should do if the client requests any URI other than '/'. It should respond with an HTTP status 404 (Not Found) and a message for the user. We put this in a function as
well, and use server.onNotFound | to tell it that it should execute it when it receives a request for a URI that
wasn't specified with server.on | .
Then we start listening for HTTP requests by using server.begin | .
During the loop, we constantly check if a new HTTP request is received by running server.handleClient | . If
handleClient detects new requests, it will automatically execute the right functions that we specified in the setup.

To test it out, upload the sketch, open a new browser tab, and browse to http://esp8266.local. You should
get a webpage saying Hello world! | . If you try to go to a different page, http://esp8266.local/test, for
instance, you should get a 404 error: 404: Not found | .

### Turning on and off an LED over Wi-Fi

We can use the web server to serve interactive pages, and to react to certain POST request. In the following example, the ESP8266 hosts a web page with a button. When the button is pressed, the browser sends a POST request to /LED. When the ESP receives such a POST request on the /LED URI, it will turn on or off the LED, and then redirect the browser back to the home page with the button.

In order to perform this redirect, the ESP has to add a Location header to the response, and use a 303 (See Other) HTTP status code.

The button to send the POST request in the browser is part of an HTML form. You have to specify the target URI to send the request to, and the request method, in this case this is "/LED" and POST respectively.

Note that I changed the content type of the response from "text/plain" to "text/html". If you send it as plain text, the browser will display it as text instead of interpreting it as HTML and showing it as a button.

#include <ESP8266WiFi.h>

#include <WiFiClient.h>

#include <ESP8266WiFiMulti.h>

#include <ESP8266mDNS.h>

#include <ESP8266WebServer.h>

ESP8266WiFiMulti wifiMulti; | // Create an instance of the ESP8266WiFiMulti class, called 'wifiMulti'
ESP8266WebServer server(80); | // Create a webserver object that listens for HTTP request on port 80

const int led = 2;

void handleRoot(); | // function prototypes for HTTP handlers
void handleLED();
void handleNotFound();

void setup(void){
Serial.begin(115200); | // Start the Serial communication to send messages to the computer
delay(10);
Serial.println('\n');

pinMode(led, OUTPUT);

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

Serial.println("Connecting ...");
int i = 0;
while (wifiMulti.run() != WL_CONNECTED) { // Wait for the Wi-Fi to connect: scan for Wi-Fi networks, and connect to the strongest of the networks above
delay(250);
Serial.print('.');
}
Serial.println('\n');
Serial.print("Connected to ");
Serial.println(WiFi.SSID()); | // Tell us what network we're connected to
Serial.print("IP address:\t");
Serial.println(WiFi.localIP()); | // Send the IP address of the ESP8266 to the computer
if (MDNS.begin("esp8266")) { | // Start the mDNS responder for esp8266.local
Serial.println("mDNS responder started");
} else {
Serial.println("Error setting up MDNS responder!");
}

server.on("/", HTTP_GET, handleRoot); // Call the 'handleRoot' function when a client requests URI "/"
server.on("/LED", HTTP_POST, handleLED); // Call the 'handleLED' function when a POST request is made

to URI "/LED"
server.onNotFound(handleNotFound); | // When a client requests an unknown URI (i.e. something
other than "/"), call function "handleNotFound"
server.begin(); | // Actually start the server
Serial.println("HTTP server started");
}

void loop(void){
server.handleClient(); | // Listen for HTTP requests from clients
}
void handleRoot() { | // When URI / is requested, send a web page with a button to
toggle the LED
server.send(200, "text/html", "<form action=\"/LED\" method=\"POST\"><input type=\"submit\" value=\"Toggle LED\"></form>");
}
void handleLED() { | // If a POST request is made to URI /LED
digitalWrite(led,!digitalRead(led)); | // Change the state of the LED
server.sendHeader("Location","/"); | // Add a header to respond with a new location for the
browser to go to the home page again
server.send(303); | // Send it back to the browser with an HTTP status 303 (See
Other) to redirect
}

void handleNotFound(){
server.send(404, "text/plain", "404: Not found"); // Send HTTP status 404 (Not Found) when there's no handler for the URI in the request
}

As you can see, the server.on function now takes three parameters: the URI, the request method (GET or POST) and the function to execute.

Connect an LED to GPIO2, and upload the sketch. Then go to http://esp8266.local/ and click the button to turn the LED on or off.

You can open the developer options in Chrome (F12) to check the HTTP request that are made when you click the button: you'll see that it first send a POST request, and then receives a 303 (See Other) HTTP status as a response. The response also has a Location header containing the URI "/", so the browser will send a GET request to the URI of this new location:

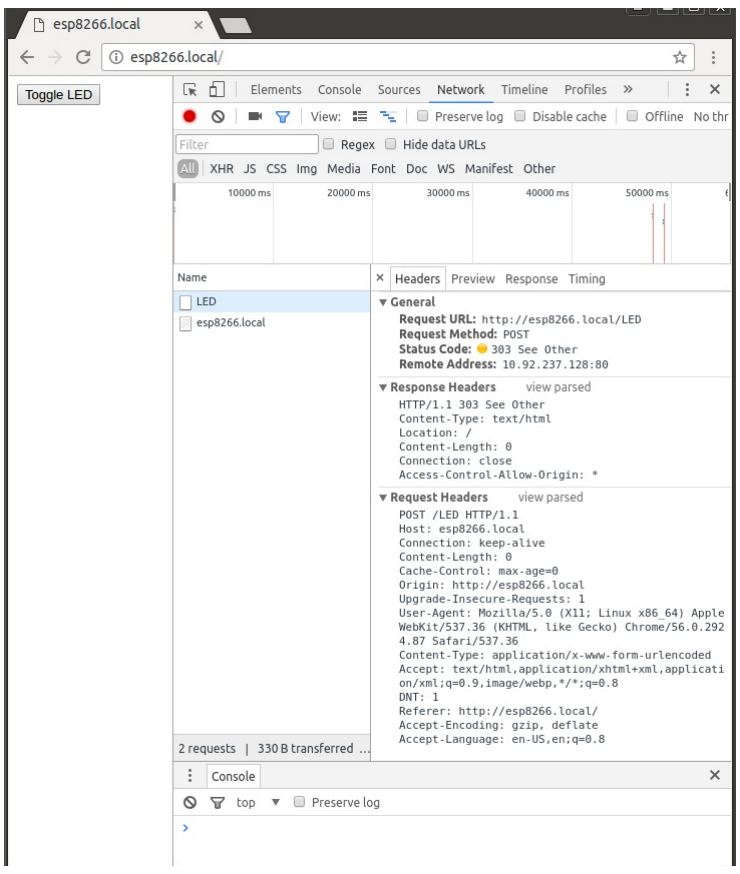
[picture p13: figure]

If you check the page source (CTRL+U), you can see the simple HTML form that's used:

<form action="/LED" method="POST">
<input type="submit" value="Toggle LED">
</form>

### Sending data to the ESP using HTTP POST

In the previous example, we sent an empty POST request to the ESP8266. In the previous chapter however, I explained that it's possible to send all kinds of data in the body of the POST request.

In this example, I'll show you how to send a username and a password to the ESP. The ESP will then check if they are correct, and respond to the request with the appropriate page.

#include <ESP8266WiFi.h>

#include <WiFiClient.h>

#include <ESP8266WiFiMulti.h>

#include <ESP8266mDNS.h>

#include <ESP8266WebServer.h>

ESP8266WiFiMulti wifiMulti; | // Create an instance of the ESP8266WiFiMulti class, called 'wifiMulti'
ESP8266WebServer server(80); | // Create a webserver object that listens for HTTP request on port 80
void handleRoot(); | // function prototypes for HTTP handlers
void handleLogin();

void handleNotFound();

void setup(void){
Serial.begin(115200); | // Start the Serial communication to send messages to the computer
delay(10);
Serial.println('\n');

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

Serial.println("Connecting ...");
int i = 0;
while (wifiMulti.run() != WL_CONNECTED) { // Wait for the Wi-Fi to connect: scan for Wi-Fi networks, and connect to the strongest of the networks above
delay(250);
Serial.print('.');
}
Serial.println('\n');
Serial.print("Connected to ");
Serial.println(WiFi.SSID()); | // Tell us what network we're connected to
Serial.print("IP address:\t");
Serial.println(WiFi.localIP()); | // Send the IP address of the ESP8266 to the computer
if (MDNS.begin("esp8266")) { | // Start the mDNS responder for esp8266.local
Serial.println("mDNS responder started");
} else {
Serial.println("Error setting up MDNS responder!");
}
server.on("/", HTTP_GET, handleRoot); | // Call the 'handleRoot' function when a client requests
URI "/"
server.on("/login", HTTP_POST, handleLogin); // Call the 'handleLogin' function when a POST request is made to URI "/login"
server.onNotFound(handleNotFound); | // When a client requests an unknown URI (i.e. something
other than "/"), call function "handleNotFound"
server.begin(); | // Actually start the server
Serial.println("HTTP server started");
}

void loop(void){
server.handleClient(); | // Listen for HTTP requests from clients
}
void handleRoot() { | // When URI / is requested, send a web page with a button
to toggle the LED
server.send(200, "text/html", "<form action=\"/login\" method=\"POST\"><input type=\"text\" name=\"username\" placeholder=\"Username\"></br><input type=\"password\" name=\"password\" placeholder=\"Password\"></br><input type=\"submit\" value=\"Login\"></form><p>Try 'John Doe' and 'password123' ...</p>");
}
void handleLogin() { | // If a POST request is made to URI /login
if( ! server.hasArg("username") || ! server.hasArg("password")
|| server.arg("username") == NULL || server.arg("password") == NULL) { // If the POST request doesn't have username and password data
server.send(400, "text/plain", "400: Invalid Request"); | // The request is invalid, so send
HTTP status 400
return;
}
if(server.arg("username") == "John Doe" && server.arg("password") == "password123") { // If both the username and the password are correct
server.send(200, "text/html", "<h1>Welcome, " + server.arg("username") + "!</h1><p>Login successful</p>");
} else { | // Username and
password don't match
server.send(401, "text/plain", "401: Unauthorized");
}
}

void handleNotFound(){
server.send(404, "text/plain", "404: Not found"); // Send HTTP status 404 (Not Found) when there's no handler for the URI in the request
}

The HTML in handleRoot is:

<form action="/login" method="POST">
<input type="text" name="username" placeholder="Username"></br> <input type="password" name="password" placeholder="Password"></br> <input type="submit" value="Login">
</form>
<p>
Try 'John Doe' and 'password123' ... </p>

Upload the sketch and go to http://esp8266.local/, then type 'John Doe' into the username field, and 'password123' into the password field, and click 'Login'. You should get a welcome screen. If you leave on or both of the fields blank, you should get a 400 (Bad Request) error. If you enter a wrong username or password, you should get a 401 (Unauthorized) error.

The data of the POST body can be accessed using server.arg("key") | , and you can check if a specific key
exists using server.hasArg("key") | . The key name on the ESP8266 corresponds to the name argument in
the HTML form on the web page.

When we get a POST request, we first check if the necessary arguments (username and password) are present. If that's not the case, we send a 400 (Invalid Request) status.
Then we check if the credentials match 'John Doe' & 'password123'. If that's the case, we respond with a status 200 (Ok) and a welcome page. If the username and/or password doesn't match, we send a 401 (Unauthorized) status.

### Inline functions

In the previous examples, we passed handleRoot | and handleNotFound | to the server.on | function as a
parameter (callback function). In some cases however, it's more readable to just write the definition of the function inline, like so:

void setup(){
// ...
server.onNotFound([](){
server.send(404, "text/plain", "404: Not found"); });
}

## SPI Flash File System

Up until now, we've always included the HTML for our web pages as string literals in our sketch. This makes our code very hard to read, and you'll run out of memory rather quickly.
If you remember the introduction, I mentioned the Serial Peripheral Interface Flash File System, or SPIFFS for short. It's a light-weight file system for microcontrollers with an SPI flash chip. The on-board flash chip of the ESP8266 has plenty of space for your webpages, especially if you have the 1MB, 2MB or 4MB version.

SPIFFS let's you access the flash memory as if it was a normal file system like the one on your computer (but much simpler of course): you can read and write files, create folders ...

The easiest way to learn how to use SPIFFS is to look at some examples. But a file server with no files to serve is pretty pointless, so I'll explain how to upload files to the SPIFFS first.

### Uploading files to SPIFFS

To select the right files to upload, you have to place them in a folder called data, inside the sketch folder of your project: Open your sketch in the Arduino IDE, and hit CTRL+K. Wait for a file explorer window to open, and create a new folder named data. Copy your files over to this folder. (Only use small files like text files or icons. There's not enough space for large photos or videos.)
Next, select all files in the folder (CTRL+A) and check the size of all files combined (don't forget subfolders). Go to the Arduino IDE again, and under Tools > Flash Size, select an option with the right flash size for your board, and a SPIFFS size that is larger than the size of your data folder.
Then upload the sketch. When that's finished, make sure that the Serial Monitor is closed, then open the Tools menu, and click ESP8266 sketch data upload. If your ESP has auto-reset and auto-program, it should work automatically, if you don't have auto-program, you have to manually enter program mode before uploading the data to SPIFFS. The procedure is exactly the same as entering program mode before uploading a sketch.

If you get an error saying SPIFFS_write error(-10001): File system is full , this means that your files are too large to fit into the SPIFFS memory. Select a larger SPIFFS size under Tools > Flash Size, or delete some files.
Even if your computer says that the files are smaller than the selected SPIFFS size, you can still get this error: this has to do with block sizes, and metadata like file and folder names that take up space as well.

If you change the SPIFFS size, you have to reupload your sketch, because when you change the SPIFFS size, the memory location will be different. The program has to know the updated SPIFFS address offset to be able to read the files.

### SPIFFS File Server

The following example is a very basic file server: it just takes the URI of the HTTP request, checks if the URI points to a file in the SPIFFS, and if it finds the file, it sends it as a response.

#include <ESP8266WiFi.h>

#include <WiFiClient.h>

#include <ESP8266WiFiMulti.h>

#include <ESP8266mDNS.h>

#include <ESP8266WebServer.h>

#include <FS.h> | // Include the SPIFFS library

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

String getContentType(String filename); // convert the file extension to the MIME type
bool handleFileRead(String path); | // send the right file to the client (if it exists)

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

delay(250);
Serial.print('.');
}
Serial.println('\n');
Serial.print("Connected to ");
Serial.println(WiFi.SSID()); | // Tell us what network we're connected to
Serial.print("IP address:\t");
Serial.println(WiFi.localIP()); | // Send the IP address of the ESP8266 to the computer
if (MDNS.begin("esp8266")) { | // Start the mDNS responder for esp8266.local
Serial.println("mDNS responder started");
} else {
Serial.println("Error setting up MDNS responder!");
}
SPIFFS.begin(); | // Start the SPI Flash Files System
server.onNotFound([]() { | // If the client requests any URI
if (!handleFileRead(server.uri())) | // send it if it exists
server.send(404, "text/plain", "404: Not Found"); // otherwise, respond with a 404 (Not Found) error
});
server.begin(); | // Actually start the server
Serial.println("HTTP server started");
}

void loop(void) {
server.handleClient();
}

String getContentType(String filename) { // convert the file extension to the MIME type if (filename.endsWith(".html")) return "text/html";
else if (filename.endsWith(".css")) return "text/css";
else if (filename.endsWith(".js")) return "application/javascript";
else if (filename.endsWith(".ico")) return "image/x-icon";
return "text/plain";
}

bool handleFileRead(String path) { // send the right file to the client (if it exists) Serial.println("handleFileRead: " + path);
if (path.endsWith("/")) path += "index.html"; | // If a folder is requested, send the index file
String contentType = getContentType(path); | // Get the MIME type
if (SPIFFS.exists(path)) { | // If the file exists
File file = SPIFFS.open(path, "r"); | // Open it
size_t sent = server.streamFile(file, contentType); // And send it to the client
file.close(); | // Then close the file again
return true;
}
Serial.println("\tFile Not Found");
return false; | // If the file doesn't exist, return false
}
As you can see, we don't use server.on | in this example. Instead, we use server.onNotFound | : this will match
any URI, since we didn't declare any specific URI handlers like in the previous server examples. When a URI is requested, we call the function handleFileRead | . This function checks if the URI of the HTTP

request is the path to an existing file in the SPIFFS. If that's the case, it sends the file back to the client. If the path doesn't exist, it returns false, and a 404 (Not Found) HTTP status will be sent.

The MIME type for the different files is based on the file extension.
You could add other file types as well. For instance:

String getContentType(String filename){ if(filename.endsWith(".htm")) return "text/html";
else if(filename.endsWith(".html")) return "text/html";
else if(filename.endsWith(".css")) return "text/css";
else if(filename.endsWith(".js")) return "application/javascript"; else if(filename.endsWith(".png")) return "image/png";
else if(filename.endsWith(".gif")) return "image/gif";
else if(filename.endsWith(".jpg")) return "image/jpeg";
else if(filename.endsWith(".ico")) return "image/x-icon"; else if(filename.endsWith(".xml")) return "text/xml";
else if(filename.endsWith(".pdf")) return "application/x-pdf"; else if(filename.endsWith(".zip")) return "application/x-zip"; else if(filename.endsWith(".gz")) return "application/x-gzip"; return "text/plain";
}

This example is adapted from the FSBrowser example by Hristo Gochkov.

### Compressing files

The ESP8266's flash memory isn't huge, and most text files, like html, css etc. can be compressed by quite a large factor. Modern web browsers accept compressed files as a response, so we'll take advantage of this by uploading compressed versions of our html and icon files to the SPIFFS, in order to save space and bandwidth.

To do this, we need to add the GNU zip file type to our list of MIME types:

String getContentType(String filename){
if(filename.endsWith(".html")) return "text/html";
else if(filename.endsWith(".css")) return "text/css";
else if(filename.endsWith(".js")) return "application/javascript"; else if(filename.endsWith(".ico")) return "image/x-icon";
else if(filename.endsWith(".gz")) return "application/x-gzip"; return "text/plain";
}

And we need to change our handleFileRead function as well:

bool handleFileRead(String path){ // send the right file to the client (if it exists) Serial.println("handleFileRead: " + path);
if(path.endsWith("/")) path += "index.html"; | // If a folder is requested, send the index
file
String contentType = getContentType(path); | // Get the MIME type
String pathWithGz = path + ".gz";
if(SPIFFS.exists(pathWithGz) || SPIFFS.exists(path)){ // If the file exists, either as a compressed archive, or normal
if(SPIFFS.exists(pathWithGz)) | // If there's a compressed version available
path += ".gz"; | // Use the compressed version
File file = SPIFFS.open(path, "r"); | // Open the file
size_t sent = server.streamFile(file, contentType); | // Send it to the client
file.close(); | // Close the file again
Serial.println(String("\tSent file: ") + path);
return true;
}
Serial.println(String("\tFile Not Found: ") + path);
return false; | // If the file doesn't exist, return false
}

Now, try compressing some of the files to the GNU zip format (.gz), and uploading them to SPIFFS. Or you can just download the new data folder (unzip it first).
Every time a client requests a certain file, the ESP will check if a compressed version is available. If so, it will use that instead of the uncompressed file. The output in the Serial Monitor should look something like this:

handleFileRead: /
Sent file: /index.html.gz
handleFileRead: /main.css
Sent file: /main.css
handleFileRead: /JavaScript.js
Sent file: /JavaScript.js
handleFileRead: /folder/JavaScript.js Sent file: /folder/JavaScript.js handleFileRead: /favicon.ico
Sent file: /favicon.ico.gz

It automatically detected that it had to send the compressed versions of index.html and favicon.ico.

## Uploading files to the server

There are scenarios where you may want to upload new files to the server from within a browser, without having to connect to the ESP8266 over USB in order to flash a new SPIFFS image.
In this chapter, I'll show you how to use HTML forms and POST requests to upload or edit files to our little ESP server.

### Client: HTML form

The easiest way to upload files is by using an HTML form, just like in the first server examples, where we used forms to turn on/off LEDs, and to send the login credentials back to the server. If you choose a file input, you automatically get a file picker, and the browser will send the right POST request to the server, with the file attached.

<form method="post" enctype="multipart/form-data">
<input type="file" name="name">
<input class="button" type="submit" value="Upload"> </form>

### Server

In the ESP code, we have to add a handler to our server that handles POST requests to the /upload URI. When it receives a POST request, it sends a status 200 (OK) back to the client to start receiving the file,

and then write it to the SPIFFS. When the file is uploaded successfully, it redirects the client to a success page.
The relevant new code is found in the setup | and the handleFileUpload | function.

#include <ESP8266WiFi.h>

#include <WiFiClient.h>

#include <ESP8266WiFiMulti.h>

#include <ESP8266mDNS.h>

#include <ESP8266WebServer.h>

#include <FS.h> | // Include the SPIFFS library

ESP8266WiFiMulti wifiMulti; | // Create an instance of the ESP8266WiFiMulti class, called 'wifiMulti'
ESP8266WebServer server(80); | // Create a webserver object that listens for HTTP request on port 80
File fsUploadFile; | // a File object to temporarily store the received file

String getContentType(String filename); // convert the file extension to the MIME type
bool handleFileRead(String path); | // send the right file to the client (if it exists)
void handleFileUpload(); | // upload a new file to the SPIFFS

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

Serial.println("Connecting ...");
int i = 0;
while (wifiMulti.run() != WL_CONNECTED) { // Wait for the Wi-Fi to connect delay(1000);
Serial.print(++i); Serial.print(' ');
}
Serial.println('\n');
Serial.print("Connected to ");
Serial.println(WiFi.SSID()); | // Tell us what network we're connected to
Serial.print("IP address:\t");
Serial.println(WiFi.localIP()); | // Send the IP address of the ESP8266 to the computer
if (!MDNS.begin("esp8266")) { | // Start the mDNS responder for esp8266.local
Serial.println("Error setting up MDNS responder!");
}
Serial.println("mDNS responder started");
SPIFFS.begin(); | // Start the SPI Flash Files System
server.on("/upload", HTTP_GET, []() { | // if the client requests the upload page
if (!handleFileRead("/upload.html")) | // send it if it exists
server.send(404, "text/plain", "404: Not Found"); // otherwise, respond with a 404 (Not Found) error

});

server.on("/upload", HTTP_POST, | // if the client posts to the upload page
[](){ server.send(200); }, | // Send status 200 (OK) to tell the client we
are ready to receive
handleFileUpload | // Receive and save the file
);
server.onNotFound([]() { | // If the client requests any URI
if (!handleFileRead(server.uri())) | // send it if it exists
server.send(404, "text/plain", "404: Not Found"); // otherwise, respond with a 404 (Not Found) error
});
server.begin(); | // Actually start the server
Serial.println("HTTP server started");
}

void loop() {
server.handleClient();
}

String getContentType(String filename) { // convert the file extension to the MIME type if (filename.endsWith(".html")) return "text/html";
else if (filename.endsWith(".css")) return "text/css";
else if (filename.endsWith(".js")) return "application/javascript";
else if (filename.endsWith(".ico")) return "image/x-icon";
else if (filename.endsWith(".gz")) return "application/x-gzip";
return "text/plain";
}

bool handleFileRead(String path) { // send the right file to the client (if it exists) Serial.println("handleFileRead: " + path);
if (path.endsWith("/")) path += "index.html"; | // If a folder is requested, send the index
file
String contentType = getContentType(path); | // Get the MIME type
String pathWithGz = path + ".gz";
if (SPIFFS.exists(pathWithGz) || SPIFFS.exists(path)) { // If the file exists, either as a compressed archive, or normal
if (SPIFFS.exists(pathWithGz)) | // If there's a compressed version available
path += ".gz"; | // Use the compressed verion
File file = SPIFFS.open(path, "r"); | // Open the file
size_t sent = server.streamFile(file, contentType); | // Send it to the client
file.close(); | // Close the file again
Serial.println(String("\tSent file: ") + path);
return true;
}
Serial.println(String("\tFile Not Found: ") + path); // If the file doesn't exist, return false return false;
}

void handleFileUpload(){ // upload a new file to the SPIFFS
HTTPUpload& upload = server.upload();
if(upload.status == UPLOAD_FILE_START){
String filename = upload.filename;
if(!filename.startsWith("/")) filename = "/"+filename;
Serial.print("handleFileUpload Name: "); Serial.println(filename);
fsUploadFile = SPIFFS.open(filename, "w"); | // Open the file for writing in SPIFFS (create
if it doesn't exist)
filename = String();
} else if(upload.status == UPLOAD_FILE_WRITE){
if(fsUploadFile)
fsUploadFile.write(upload.buf, upload.currentSize); // Write the received bytes to the file } else if(upload.status == UPLOAD_FILE_END){
if(fsUploadFile) { | // If the file was successfully created
fsUploadFile.close(); | // Close the file again
Serial.print("handleFileUpload Size: "); Serial.println(upload.totalSize);
server.sendHeader("Location","/success.html"); | // Redirect the client to the success page
server.send(303);
} else {
server.send(500, "text/plain", "500: couldn't create file");
}
}
}
The handleFileUpload | function just writes the file attached to the POST request to SPIFFS.
If you wan to use other file types as well, you can just add them to the getContentType | function.

### Uploading files

To upload a new file to the ESP, or to update an existing file, just go to http://esp8266.local/upload, click the Choose File button, select the file you wish to upload, and click Upload. You can now enter the URL into the URL bar, and open the new file.

### A note on safety

This example isn't very secure (obviously). Everyone that can connect to the ESP can upload new files, or edit the existing files and insert XSS code, for example. There's also not a lot of error checking/handling, like checking if there's enough space in the SPIFFS to upload a new file, etc.

### Advanced example

The code for these SPIFFS server examples comes (for the most part) from an example written by Hristo Gochkov. You can find it under File > Examples > ESP8266WebServer > FSBrowser. It has a web interface for browsing and editing files in your browser, and has some other nice features as well.

## Over The Air Updates

Uploading over Serial is fine during development, when you have access to the Serial pins and the USB port. But once your project is finished, and you put it inside an enclosure, it not that easy to upload updates with bug fixes or new features.
A solution to this problem is Over The Air updating, or OTA for short. As the name implies, this technology allows you to upload new code over Wi-Fi, instead of Serial.
The only disadvantage is that you have to explicitly add the code for it to every sketch you upload. You also need a flash chip that is twice the size of your sketch, so it won't work for 512kB boards. (It has to download the new sketch while still running the old code.)
Let's take a look at an example ...

### Blink OTA

The following example is basically Blink Without Delay, but with the necessary OTA and Wi-Fi code added as well.

#include <ESP8266WiFi.h>

#include <ESP8266WiFiMulti.h>

#include <ArduinoOTA.h>

ESP8266WiFiMulti wifiMulti; // Create an instance of the ESP8266WiFiMulti class, called 'wifiMulti'

const byte led = 13;

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

Serial.println("Connecting ...");
int i = 0;
while (wifiMulti.run() != WL_CONNECTED) { // Wait for the Wi-Fi to connect delay(250);
Serial.print('.');
}
Serial.println('\n');
Serial.print("Connected to ");
Serial.println(WiFi.SSID()); | // Tell us what network we're connected to
Serial.print("IP address:\t");
Serial.println(WiFi.localIP()); | // Send the IP address of the ESP8266 to the computer

ArduinoOTA.setHostname("ESP8266");
ArduinoOTA.setPassword("esp8266");

ArduinoOTA.onStart([]() {
Serial.println("Start");
});
ArduinoOTA.onEnd([]() {
Serial.println("\nEnd");
});
ArduinoOTA.onProgress([](unsigned int progress, unsigned int total) { Serial.printf("Progress: %u%%\r", (progress / (total / 100)));
});
ArduinoOTA.onError([](ota_error_t error) {
Serial.printf("Error[%u]: ", error);
if (error == OTA_AUTH_ERROR) Serial.println("Auth Failed");
else if (error == OTA_BEGIN_ERROR) Serial.println("Begin Failed"); else if (error == OTA_CONNECT_ERROR) Serial.println("Connect Failed"); else if (error == OTA_RECEIVE_ERROR) Serial.println("Receive Failed"); else if (error == OTA_END_ERROR) Serial.println("End Failed");
});
ArduinoOTA.begin();
Serial.println("OTA ready");

pinMode(led, OUTPUT);
digitalWrite(led, 1);
}

unsigned long previousTime = millis();

const unsigned long interval = 1000;

void loop() {
ArduinoOTA.handle();

unsigned long diff = millis() - previousTime;
if(diff > interval) {
digitalWrite(led, !digitalRead(led)); // Change the state of the LED previousTime += diff;
}
}

Add your Wi-Fi credentials, and upload the sketch over Serial. Connect an LED (+ resistor) to pin 13. Then restart the IDE (you have to close all windows). Go to Tools > Port, and you should get a new option: Network Ports: ESP8266 at 192.168.1.x. Select it.

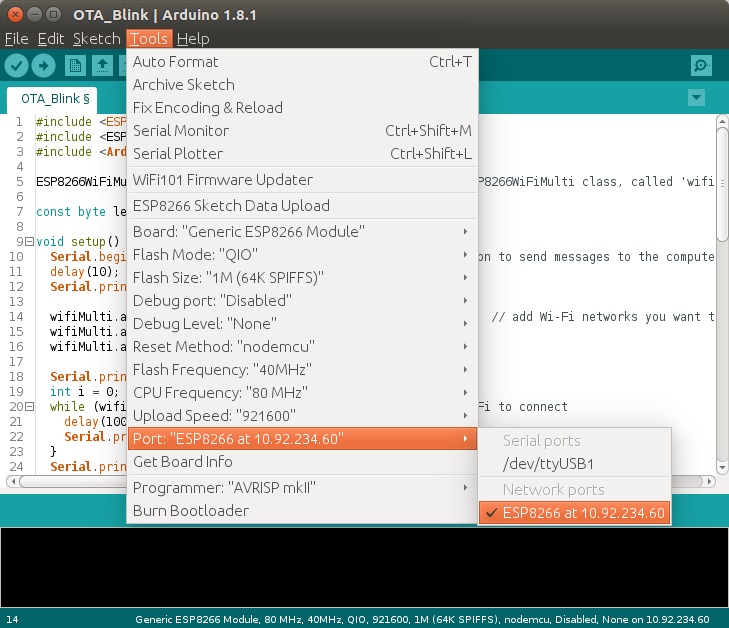
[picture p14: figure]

Next, change the interval on line 59 from 1000 to 500 milliseconds, and click upload. You should get a password prompt: enter "esp8266". This password is set on line 31, so you can change it if you want to. You can also delete line 31 altogether to use it without a password, but it's not recommended - for obvious security reasons.

The sketch should upload just fine, and once the ESP has reset itself, the LED should blink twice as fast.

Once in a while, you might get an error saying [ERROR]: No Answer . If this happens, just enter the password, and try again.
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

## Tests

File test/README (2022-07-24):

This directory is intended for PlatformIO Unit Testing and project tests.

Unit Testing is a software testing method by which individual units of
source code, sets of one or more MCU program modules together with associated
control data, usage procedures, and operating procedures, are tested to
determine whether they are fit for use. Unit testing finds problems early
in the development cycle.

More information about PlatformIO Unit Testing:
- https://docs.platformio.org/page/plus/unit-testing.html

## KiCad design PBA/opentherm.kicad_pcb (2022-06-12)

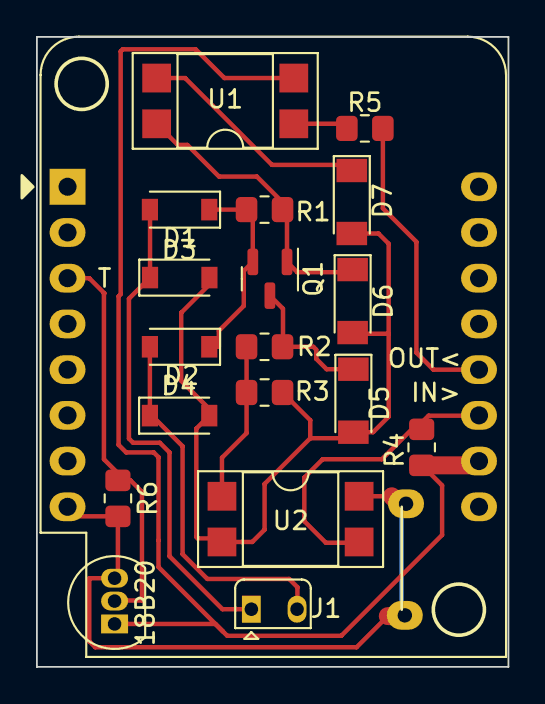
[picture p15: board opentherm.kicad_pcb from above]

Board: 2 copper layers, 26.2 x 35.0 mm, 19 parts (0 on the bottom side), 14 nets.

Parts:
18B20: Conn_01x03; TO-92L_Inline
D1, D2, D3, D4: 1N4148W; D_SOD-123
D5: 4V7; D_MiniMELF
D6: 15v; D_MiniMELF
D7: 4V3; D_MiniMELF
J1: OT1_OT2; Heraeus_TO-92-2
Q1: BC858; SOT-23
R1, R5: 330; R_0805_2012Metric_Pad1.20x1.40mm_HandSolder
R2: 220; R_0805_2012Metric_Pad1.20x1.40mm_HandSolder
R3: 100; R_0805_2012Metric_Pad1.20x1.40mm_HandSolder
R4: 1k5; R_0805_2012Metric_Pad1.20x1.40mm_HandSolder
R6: 4k7; R_0805_2012Metric_Pad1.20x1.40mm_HandSolder
U1, U2: PC817; DIP-4_W7.62mm_SMDSocket_SmallPads
U3: WeMos_D1_mini; WEMOS_D1_mini_light

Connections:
GND: 18B20.1, R4.1, U1.2, U3.10 (GND)
unnamed: 18B20.2, R6.1, U3.3 (D0)
unnamed: D1.1 (K), D2.1 (K), Q1.2 (E), R1.1
unnamed: D3.1 (K), D4.1 (K), D5.2 (A), D6.2 (A), D7.2 (A), R3.2, U2.2
unnamed: D5.1 (K), Q1.3 (C), R2.1
unnamed: D6.1 (K), Q1.1 (B), R1.2, U1.4
unnamed: D7.1 (K), U1.3
unnamed: R2.2, R3.1, U2.1
unnamed: R5.1, U1.1
VCC: 18B20.3, R6.2, U2.4, U3.8 (3V3)
in: R5.2, U3.12 (D3)
ot1: D1.2 (A), D3.2 (A), J1.1
ot2: D2.2 (A), D4.2 (A), J1.2
out: R4.2, U2.3, U3.11 (D4)

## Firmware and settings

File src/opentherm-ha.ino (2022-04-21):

/*************************************************************
  This example runs directly on ESP8266 chip.

  Please be sure to select the right ESP8266 module
  in the Tools -> Board -> WeMos D1 Mini

  Adjust settings in Config.h before run
 *************************************************************/

//#include <Arduino.h>
#include <ESP8266WiFi.h>
#include <OneWire.h>
#include <DallasTemperature.h>
#include <PubSubClient.h>
#include <OpenTherm.h>
#include "config.h"
//#include <ArduinoHA.h>  //HomeAssistant
#include <WebSerial.h>

#include <WiFiClient.h>

// for ota
#include <ESPAsyncWebServer.h>
#include <ESPAsyncTCP.h>
//#include <ESPAsyncUDP.h>
//#include <ESPAsyncDNSServer.h>

AsyncWebServer webserver(wwwport);
// for ota webs

const unsigned long extTempTimeout_ms = 180 * 1000,
                    statusUpdateInterval_ms = 0.9 * 1000,
                    spOverrideTimeout_ms = 180 * 1000,
                    mqttUpdateInterval_ms = 16 * 1000,
                    temp_NEWS_interval_reduction_time_ms = 30 * 60 * 1000, // time to laps between temp_NEWS reduction by 5%
                    mqtt_offline_reconnect_after_ms = 15 * 60 * 1000,      // time when mqtt is offline to wait for next reconnect (15minutes)
                    save_config_every = 15 * 60 * 1000,                    // time saveing config values in eeprom (15minutes)
                    WiFiinterval = 30 * 1000;

// upper and lower bounds on heater level
const float ophi = 65,               // upper max heat water
            oplo = 30,               // lower min heat water
            opcohi = 60,             // upper max heat boiler to CO
            opcolo = oplo,           // lower min heat boiler to CO
            cutoffhi = 20,           // upper max cut-off temp above is heating CO disabled -range +-20
            cutofflo = -cutoffhi,    // lower min cut-off temp above is heating CO disabled
            roomtemphi = 25,         // upper max to set of room temperature
            roomtemplo = 15,         // lower min to set of room temperature
            noCommandSpOverride = 32; //heating water temperature for fail mode (no external temp provided) for co

unsigned int runNumber = 0, // count of restarts
             publishhomeassistantconfig = 4,                               // licznik wykonan petli -strat od 0
             publishhomeassistantconfigdivider = 5;                        // publishhomeassistantconfig % publishhomeassistantconfigdivider -publikacja gdy reszta z dzielenia =0 czyli co te ilosc wykonan petli opoznionej update jest wysylany config

float dhwTarget = 51, // domyslna temperatura docelowa wody uzytkowej
      sp = 20.5,       // set point roomtemp
      roomtemp = 21,     // current temperature
      roomtemp_last = 0, // prior temperature
      ierr = 25,         // integral error
      dt = 0,            // time between measurements
      //       op = 0, //PID controller output
      retTemp = 0,                         // return temperature
      temp_NEWS = 0,                       // avg temperatura outside -getting this from mqtt topic as averange from 4 sensors North West East South
      cutOffTemp = 2,                      // outside temp setpoint to cutoff heating co. CO heating is disabled if outside temp (temp_NEWS) is above this value
      op_override = noCommandSpOverride, // boiler tempset on heat mode
      flame_level = 0,
      tempBoiler = 0,
      tempBoilerSet = op_override, // temp boiler set -mainly used in auto mode and for display on www actual temp
      tempCWU = 0,
      pressure = 0;


String LastboilerResponseError;

int temp_NEWS_count = 0,
    mqtt_offline_retrycount = 0,
    mqtt_offline_retries = 10; // retries to mqttconnect before timewait

unsigned long ts = 0, new_ts = 0, // timestamp
              lastUpdate = 0,
              lastUpdatemqtt = 0,
              lastTempSet = 0,
              lastcutOffTempSet = 0,
              lastNEWSSet = 0,
              lastmqtt_reconnect = 0,
              lastSaveConfig = 0,
              lastSpSet = 0,
              WiFipreviousMillis = 0,
              start_flame_time = 0;    //Flame Starts work

float    flame_used_power = 0;         //for count powerkWh between samples (boiler rated*flame power) use integer end when div use % do get decimal value

bool heatingEnabled = true,
     enableHotWater = true,
     CO_PumpWorking = false, // value from mqtt -if set co heating is disabled -second heating engine is working (in my case Wood/Carbon heater)
     automodeCO = false,     // tryb automatyczny zalezny od temp zewnetrznej i pracy pompy CO kotla weglowego
     receivedmqttdata = false,
     tmanual = false,
     status_Fault,
     status_CHActive,
     status_WaterActive,
     status_FlameOn,
     status_Cooling,
     status_Diagnostic;

OneWire oneWire(ROOM_TEMP_SENSOR_PIN);
DallasTemperature sensors(&oneWire);
OpenTherm ot(OT_IN_PIN, OT_OUT_PIN);
WiFiClient espClient;
PubSubClient client(espClient);

// ESP8266WebServer server(80);

#include "websrv_ota.h"

void recvMsg(uint8_t *data, size_t len)
{ // for WebSerial
  WebSerial.println("Received Data...");
  String d = "";
  for (int i = 0; i < len; i++)
  {
    d += char(data[i]);
  }
  WebSerial.println("Received: " + String(d));
  if (d == "ON")
  {
    //  digitalWrite(LED, HIGH);
  }
  if (d == "OFF")
  {
    //  digitalWrite(LED, LOW);
  }
  if (d == "RESTART")
  {
    WebSerial.println(F("OK. Restarting... by command..."));
    restart();
  }
  if (d == "RECONNECT")
  {
    reconnect();
  }
  if (d == "ROOMTEMP+")
  {
    WebSerial.print("Change t from: " + String(roomtemp));
    roomtemp = roomtemp + 1;
    tmanual = true;
    lastTempSet = millis();
    WebSerial.print(" to: " + String(roomtemp));
  }
  if (d == "ROOMTEMP-")
  {
    WebSerial.print("Change t from: " + String(roomtemp));
    roomtemp = roomtemp - 1;
    lastTempSet = millis();
    tmanual = true;
    WebSerial.print(" to: " + String(roomtemp));
  }
  if (d == "ROOMTEMP0")
  {
    WebSerial.print("Change t from: " + String(roomtemp));
    tmanual = false;
    lastTempSet = millis();
    WebSerial.print(" to: " + String(roomtemp));
  }
  if (d == "SAVE")
  {
    WebSerial.println(F("Saving config to EEPROM memory by command..."));
    WebSerial.println("Size CONFIG: " + String(sizeof(CONFIGURATION)));
    saveConfig();
  }
  if (d == "RESET-CONFIG")
  {
    WebSerial.println(F("RESET config to DEFAULT VALUES and restart..."));
    WebSerial.println("Size CONFIG: " + String(sizeof(CONFIGURATION)));
    CONFIGURATION.version[0] = 'R';
    CONFIGURATION.version[1] = 'E';
    CONFIGURATION.version[2] = 'S';
    CONFIGURATION.version[3] = 'E';
    CONFIGURATION.version[4] = 'T';
    saveConfig();
    restart();
  }
  if (d == "LOGCONFIG")
  {
    WebSerial.println("Saved CONFIG:");
    WebSerial.println("COPUMP_GET_TOPIC " + String(CONFIGURATION.COPUMP_GET_TOPIC));

    WebSerial.println("heatingEnabled " + String(CONFIGURATION.heatingEnabled));
    WebSerial.println("enableHotWater " + String(CONFIGURATION.enableHotWater));
    WebSerial.println("automodeCO " + String(CONFIGURATION.automodeCO));
    WebSerial.println("tempBoilerSet " + String(CONFIGURATION.tempBoilerSet));
    WebSerial.println("sp: " + String(CONFIGURATION.sp));
    WebSerial.println("cutOffTemp " + String(CONFIGURATION.cutOffTemp));
    WebSerial.println("op_override" + String(CONFIGURATION.op_override));
    WebSerial.println("dhwTarget " + String(CONFIGURATION.dhwTarget));
    WebSerial.println("roomtemp " + String(CONFIGURATION.roomtemp));
    WebSerial.println("temp_NEWS " + String(CONFIGURATION.temp_NEWS));
    WebSerial.println("ssid " + String(CONFIGURATION.ssid));
    WebSerial.println("pass " + String(CONFIGURATION.pass));
    WebSerial.println("mqtt_server " + String(CONFIGURATION.mqtt_server));
    WebSerial.println("mqtt_user " + String(CONFIGURATION.mqtt_user));
    WebSerial.println("mqtt_password " + String(CONFIGURATION.mqtt_password));
    WebSerial.println("mqtt_port " + String(CONFIGURATION.mqtt_port));

    WebSerial.println("NEWS_GET_TOPIC " + String(CONFIGURATION.NEWS_GET_TOPIC));
    WebSerial.println("Size CONFIG: " + String(sizeof(CONFIGURATION)));
  }
  if (d == "CO")
  {
    // espClient.connect("esp-b2c08e/dallThermometerS");
    client.disconnect();

    espClient.stop();
    String host = "esp-b2c08e";
    if (espClient.connect("esp-b2c08e", 80))
    {
      WebSerial.println("connected]");

      WebSerial.println("[Sending a request]");
      String url = "/dallThermometerS";
      espClient.print(String("GET /") + url + " HTTP/1.1\r\n" +
                      "Host: " + host + "\r\n" +
                      "Connection: close\r\n" +
                      "\r\n");

      WebSerial.println("[Response:]");
      while (espClient.connected())
      {
        String line = espClient.readStringUntil('\r');
        WebSerial.print(line);
        WebSerial.println("Liczba: ");
        WebSerial.println(isValidNumber(line) ? String(line.toFloat()) : "NaN");
      }
      espClient.stop();
      WebSerial.println("\n[Disconnected]");
    }
    else
    {
      WebSerial.println("connection failed!]");
      espClient.stop();
    }
  }
  if (d == "HELP")
  {
    WebSerial.println(F("KOMENDY: RESTART, RECONNECT, ROOMTEMP+/-, ROOMTEMP0, SAVE, LOGCONFIG, RESET-CONFIG"));
  }
}

void IRAM_ATTR handleInterrupt()
{
  ot.handleInterrupt();
}

float getTemp()
{
  unsigned long now = millis();
  if ((now - lastTempSet) > extTempTimeout_ms)
  {
    lastTempSet = now;
    WebSerial.print(F("Update dallas temp."));
    return sensors.getTempCByIndex(0);
  }
  else
    return roomtemp;
}

// op = pid(sp, t, t_last, ierr, dt);
float pid(float sp, float pv, float pv_last, float &ierr, float dt)
{
  float KP = 10;
  float KI = 0.02;

  // calculate the error
  float error = sp - pv;
  // calculate the integral error
  ierr = ierr + KI * error * dt;
  // calculate the measurement derivative
  // float dpv = (pv - pv_last) / dt;
  // calculate the PID output
  float P = KP * error; // proportional contribution
  float I = ierr;       // integral contribution
  float op = P + I;
  // implement anti-reset windup
  if ((op < opcolo) || (op > opcohi))
  {
    I = I - KI * error * dt;
    // clip output
    op = max(opcolo, min(opcohi, op));
  }
  ierr = I;
#ifdef debug
  Serial.println("sp=" + String(sp) + " pv=" + String(pv) + " dt=" + String(dt) + " op=" + String(op) + " P=" + String(P) + " I=" + String(I));
#endif
  if (publishhomeassistantconfig % publishhomeassistantconfigdivider == 0)
    WebSerial.println("sp=" + String(sp) + " pv=" + String(pv) + " dt=" + String(dt) + " op=" + String(op) + " P=" + String(P) + " I=" + String(I) + " tNEWS=" + String(temp_NEWS));

  return op;
}

// This function calculates temperature every second.
void opentherm_update_data(unsigned long mqttdallas)
{
  // Set/Get Boiler Status
  bool enableCooling = false;
  receivedmqttdata = false;

  if (temp_NEWS < cutOffTemp)
    heatingEnabled = true;
  if (CO_PumpWorking)
    heatingEnabled = false;
  if (temp_NEWS > (cutOffTemp + 0.9))
    heatingEnabled = false;

  unsigned long response = ot.setBoilerStatus(heatingEnabled, enableHotWater, enableCooling); // enableOutsideTemperatureCompensation
  OpenThermResponseStatus responseStatus = ot.getLastResponseStatus();
  if (responseStatus != OpenThermResponseStatus::SUCCESS)
  {
    String msg = "Error: Invalid boiler response " + String(response, HEX);
#ifdef debug
    Serial.println(msg);
#endif
    WebSerial.println(msg);
    LastboilerResponseError = msg;
  }
  ot.setDHWSetpoint(dhwTarget);

  if (tmanual == false)
    roomtemp = getTemp();

  if (roomtemp == -127)
    roomtemp = sp;
  if (roomtemp_last == -127)
    roomtemp_last = sp;
  float op = 0;
  if (responseStatus == OpenThermResponseStatus::SUCCESS)
  {
    unsigned long now = millis();
    new_ts = millis();
    dt = (new_ts - ts) / 1000.0;
    ts = new_ts;
    op = pid(sp, roomtemp, roomtemp_last, ierr, dt);
    if ((now - lastSpSet <= spOverrideTimeout_ms))
    {
      op = noCommandSpOverride;
    }
    if (automodeCO)
    {
      // WebSerial.println(F("tryb AutomodeCO"));
      tempBoilerSet = op;
    }
    else
    {
      tempBoilerSet = op_override;
    }
    ot.setBoilerTemperature(tempBoilerSet);
  }

  roomtemp_last = roomtemp;

  status_Fault = ot.isFault(response);
  status_CHActive = ot.isCentralHeatingActive(response);
  status_WaterActive = ot.isHotWaterActive(response);
  bool status_flame_tmp = status_FlameOn;
  status_FlameOn = ot.isFlameOn(response);
  if (status_flame_tmp != status_FlameOn) {
    status_FlameOn? start_flame_time=millis() : start_flame_time=0;  //After change flame status If flame is on get timer, else reset timer
  }
  status_Cooling = ot.isCoolingActive(response);
  status_Diagnostic = ot.isDiagnostic(response);
  flame_level = ot.getModulation();
  tempBoiler = ot.getBoilerTemperature();
  tempCWU = ot.getDHWTemperature();
  retTemp = ot.getReturnTemperature();
  pressure = ot.getPressure();

  if (millis() - mqttdallas > mqttUpdateInterval_ms)
  {
    sensors.requestTemperatures(); // async temperature request
    WebSerial.println(F("Request Dallas temperatures..."));
  }
}
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
void loop()
{
  unsigned long now = millis() + 100; // TO AVOID compare -2>10000 which is true ??? why?
  // check mqtt is available and connected in other case check values in api.
  if (status_FlameOn) {
    flame_used_power += ((flame_level/100)*boiler_rated_kWh/((millis()-start_flame_time)/hour)*1000);
    //flame_elapsed_time = millis()-start_flame_time;
  }

  if (mqtt_offline_retrycount == mqtt_offline_retries)
  {
    if ((now - lastmqtt_reconnect) > mqtt_offline_reconnect_after_ms)
    {
      lastmqtt_reconnect = now;
      mqtt_offline_retrycount = 0;
      WebSerial.println(F("MQTT connection problem -now reset retry counter and try again..."));
    }
    else
    {
      WebSerial.println(F("MQTT connection problem -now try get temp data alternative way (room temp and NEWS temp and Carbon CO Water pump status"));
      // best place to function get values from http when mqtt is unavailable
      //lastNEWSSet = now; // reset counter news temp with alternative parse value way
      //temp_NEWS_count = 0;
    }
  }
  else
  {
    if (!client.connected())
    {
      WebSerial.println(F("MQTT connection problem -try to connect again..."));
      reconnect();
    }
    else
    {
      client.loop();
    }
  }

  if ((now - lastUpdate) > statusUpdateInterval_ms)
  {
    lastUpdate = now;
    opentherm_update_data(lastUpdatemqtt); // According OpenTherm Specification from Ihnor Melryk Master requires max 1s interval communication -przy okazji wg czasu update mqtt zrobie odczyt dallas
  }
  if (((now - lastUpdatemqtt) > mqttUpdateInterval_ms) or (receivedmqttdata == true))
  {
    lastUpdatemqtt = now;
    updateData();
  }
  //#define abs(x) ((x)>0?(x):-(x))
  if ((now - lastNEWSSet) > temp_NEWS_interval_reduction_time_ms)
  { // at every 0,5hour lower temp NEWS when no communication why -2>1800000 is true ???
    WebSerial.print("now: ");
    WebSerial.println(String(now));
    WebSerial.print("lastNEWSSet: ");
    WebSerial.println(String(lastNEWSSet));
    WebSerial.print("temp_NEWS_interval_reduction_time_ms: ");
    WebSerial.println(String(temp_NEWS_interval_reduction_time_ms));
    lastNEWSSet = now;
    temp_NEWS_count++;
    if (temp_NEWS > cutOffTemp)
    {
      temp_NEWS = temp_NEWS - temp_NEWS * 0.05;
      WebSerial.println(F("Lowering by 5% temp_NEWS (no communication) -after 10times execute every 30minutes lowered temp NEWS"));
    }
    else
    {
      temp_NEWS = cutOffTemp;
    }
    if (temp_NEWS_count > 10)
    {
      CO_PumpWorking = false; // assume that we loose mqtt connection to other system where is co pump controlled -so after 10 times lowered NEWS temp by 5% we also disable CO_Pump_Working to allow heat by this heater -default it counts 5hours no communication
      WebSerial.println(F("Force disable CO_PumpWorking flag -after 10times execute every 30minutes lowered temp NEWS"));
      temp_NEWS_count = 0;
    }
    // dobre miejsce do try get data by http api
    WebSerial.println(F("Korekta temperatury NEWS z braku połaczenia -pomniejszona o 5%"));
  }

  // if WiFi is down, try reconnecting
  if ((WiFi.status() != WL_CONNECTED) && (now - WiFipreviousMillis >= WiFiinterval))
  {
    Serial.print(now);
    Serial.println("Reconnecting to WiFi...");
    WiFi.disconnect();
    WiFi.begin(ssid, pass);
    WiFipreviousMillis = now;
  }

  if ((now - lastSaveConfig) > save_config_every)
  {
    lastSaveConfig = now;
    WebSerial.println(F("Saving config to EEPROM memory..."));
    saveConfig(); // According OpenTherm Specification from Ihnor Melryk Master requires max 1s interval communication -przy okazji wg czasu update mqtt zrobie odczyt dallas
  }

  static bool failFlag = false;
  bool fail = now - lastTempSet > extTempTimeout_ms && now - lastSpSet > spOverrideTimeout_ms + now;
  if (fail)
  {
    if (!failFlag)
    {
      failFlag = true;
#ifdef debug
      Serial.printf("Neither temperature nor setpoint provided, setting heating water to %.1f\r\n", noCommandSpOverride);
#endif
      WebSerial.println("Neither temperature nor setpoint provided, setting heating water to " + String(noCommandSpOverride));
    }

    lastSpSet = millis();
    op_override = noCommandSpOverride;
  }
  else
  {
    failFlag = false;
  }
  // webserver.handleClient(); //handle http requests
}

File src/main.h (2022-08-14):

#include "Common_symlinkFiles\common_functions.h"



#include <OneWire.h>
#include <DallasTemperature.h>

#include <OpenTherm.h>


#include <WiFiClient.h>






//#include "config.h"



OneWire oneWire(ROOM_TEMP_SENSOR_PIN);
DallasTemperature sensors(&oneWire);
OpenTherm OpenTherm(OT_IN_PIN, OT_OUT_PIN);

#define spOverrideTimeout_ms (180 * 1000)               //used in main

const unsigned long //extTempTimeout_ms = 180 * 1000,
                    statusUpdateInterval_ms = 0.9 * 1000,
            //        ,
                    temp_NEWS_interval_reduction_time_ms = 30 * 60 * 1000, // time to laps between temp_NEWS reduction by 5%
                    mqtt_offline_reconnect_after_ms = 15 * 60 * 1000,      // time when mqtt is offline to wait for next reconnect (15minutes)
                    save_config_every = 15 * 60 * 1000,                    // time saveing config values in eeprom (15minutes)
                    WiFiinterval = 30 * 1000;

// upper and lower bounds on heater level
const float noCommandSpOverride = 32; //heating water temperature for fail mode (no external temp provided) for co


float dhwTarget = 49.5, // domyslna temperatura docelowa wody uzytkowej
      roomtempSet = 20.5,       // set point roomtemp
      roomtemp = 21,     // current temperature
      roomtemp_last = 0, // prior temperature
      ierr = 0,         // integral error
      dt = 0,            // time between measurements
      //       op = 0, //PID controller output
      retTemp = 0,                         // return temperature
      temp_NEWS = InitTemp,                       // avg temperatura outside -getting this from mqtt topic as averange from 4 sensors North West East South
      cutOffTemp = 2,                      // outside temp setpoint to cutoff heating co. CO heating is disabled if outside temp (temp_NEWS) is above this value
 //     op_override = noCommandSpOverride, // boiler tempset on heat mode
      flame_level = 0,
      tempBoiler = 0,
      tempBoilerSet = noCommandSpOverride, // temp boiler set -mainly used in auto mode and for display on www actual temp
      tempCWU = 0,
      dallasTemp = 0,
      pressure = 0,
      histCWU = 5,             //histereza dla cwu -obnizenie progu aktywacji grzania
      histCO = 0,             //histereza dla co -obnizenie progu aktywacji grzania
      histlo = 0,             //min wartosc histerezy
      histhi = histerezaCOCWU,             //max wartosc histerezy
      temp_Water2 = 0;                  //remote temp lower part



unsigned long ts = 0, new_ts = 0, // timestamp
              lastUpdate = 0,
              lastTempSet = 0,
              lastcutOffTempSet = 0,
              lastNEWSSet = 0,
              lastmqtt_reconnect = 0,
              lastSaveConfig = 0,
              lastroomtempSet = 0,
              WiFipreviousMillis = 0,
              temp_Water2_time = 0;     //for remote temp water
unsigned long long start_flame_time = 0,    //Flame Starts work
                   start_flame_time_fordisplay = 0,  //for display on status card flame time
                   flame_time_total = 0,         //total sum of flametime
                   flame_time_waterTotal = 0,
                   flame_time_CHTotal = 0;

double  flame_used_power_kwh = 0,     //f or count powerkWh between samples (boiler rated*flame power) use integer end when div use % do get decimal value
        flame_used_power = 0,         //for count used energy
        flame_used_power_waterTotal = 0,
        flame_used_power_CHTotal = 0;

bool heatingEnabled = true,
     enableHotWater = true,
     CO_PumpWorking = false, // value from mqtt -if set co heating is disabled -second heating engine is working (in my case Wood/Carbon heater)
     Water_PumpWorking = false, // value from mqtt -if set water heating engine is working (in my case Wood/Carbon heater)
     automodeCO = false,     // tryb automatyczny zalezny od temp zewnetrznej i pracy pompy CO kotla weglowego
     tmanual = false,
     status_Fault = false,
     status_CHActive = false,
     status_WaterActive =false,
     status_FlameOn =false,
     status_flame_prv = false,     //previous status of flame before read new val
     status_Cooling =false,
     status_Diagnostic =false,
     ecoMode = true;


float floor1_temp = InitTemp, floor2_temp = InitTemp, floor1_tempset = InitTemp, floor2_tempset = InitTemp;



//main.cpp
void IRAM_ATTR OT_Handle_Interrupt();
float pid(float sp, float pv, float pv_last, float &ierr, float dt);
void opentherm_update_data();
void getTemp();
String Boiler_Mode();
void setup();
void loop();



//webserver_ota
// bool loadConfig();
// bool SaveConfig();
//String addusage_local_values();   //it is on commonfunc defined







//#include "common_functions.h"
#include "load_save_config.h"
#include "mqttinflux.h"
#include "update_data2web.h"

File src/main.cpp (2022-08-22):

/*************************************************************
  This example runs directly on ESP8266 chip.

  Please be sure to select the right ESP8266 module
  in the Tools -> Board -> WeMos D1 Mini

  Adjust settings in Config.h before run
 *************************************************************/

//#include <Arduino.h>
//const float InitTemp = 255;
#include "main.h"


//***********************************************************************************************************************************************************************************************
void IRAM_ATTR Handle_Interrupt()
{
  OpenTherm.handleInterrupt();
}

void IRAM_ATTR processResponse(unsigned long response, OpenThermResponseStatus responseStatus)
{
  OpenTherm.process();
  #ifdef debug
  sprintf(log_chars, "OpenTherm response: %s, OpenTherm OTStatus: %s", String(response).c_str(), OpenTherm.statusToString(responseStatus));
  log_message(log_chars);
#endif
}
//***********************************************************************************************************************************************************************************************
// op = pid(sp, t, t_last, ierr, dt);
float pid(float sp, float pv, float pv_last, float &ierr, float dt)
{ //Generate curve heating based on roomtemp/roomtempset
  float KP = 10;
  float KI = 0.02;

  // calculate the error
  float error = sp - pv;
  // calculate the integral error
  ierr = ierr + KI * error * dt;
  // calculate the measurement derivative
  // float dpv = (pv - pv_last) / dt;
  // calculate the PID output
  float P = KP * error; // proportional contribution
  float I = ierr;       // integral contribution
  float op = P + I;
  // implement anti-reset windup
  if ((op < opcolo) || (op > opcohi))
  {
    I = I - KI * error * dt;
    // clip output

    op = max(opcolo, min(opcohi, op));
  }
  ierr = I;
  #ifdef debug
  sprintf(log_chars, "sp=%s, pv=%s, dt=%s, op=%s, P=%s, I=%s, tNEWS=%s", String(sp).c_str(), String(pv).c_str(), String(dt).c_str(), String(op).c_str(), String(P).c_str(), String(I).c_str(), String(temp_NEWS).c_str());
  log_message(log_chars);
  #endif
  return op;
}
//***********************************************************************************************************************************************************************************************
// This function calculates temperature every second.
void opentherm_update_data()
{
  log_message((char*)F("Update_OpenTherm_data"));
  // Set/Get Boiler Status
  bool enableCooling = false;
  receivedmqttdata = false;
  float histCOtmp = histCO,
        histCWUtmp = histCWU;
  bool COHeat = false;
  if (ecoMode) {opcohi = ecohi;} else {opcohi = opcohistatic;}
  if (tempBoilerSet > opcohi) {tempBoilerSet = opcohi;}

  getTemp(); //default returns roomtemp (avg) and as global sp=roomtempset (avg), roomtemp is also global var
  float op = tempBoilerSet;
  if (heatingEnabled) {
    //  if (!automodeCO) {
    //this will remove tempset avg from floors tempBoilerSet = op_override;  //for no automode
    if (temp_NEWS < cutOffTemp)
      COHeat = true;
    if (CO_PumpWorking)
      COHeat = false;
    if (temp_NEWS > (cutOffTemp + cutoff_histereza))
      COHeat = false;
    //  } else
    if (automodeCO) {
      if (roomtemp < (roomtempSet + 0.6) && COHeat) COHeat = true; else COHeat = false;
      //based on roomtemp<roomtemset
      op = 0;
      unsigned long now = millis();
      new_ts = millis();
      dt = (new_ts - ts) / 1000.0;
      ts = new_ts;
      op = pid(roomtempSet, roomtemp, roomtemp_last, ierr, dt);
      if ((now - lastroomtempSet <= spOverrideTimeout_ms))
      {
        op = noCommandSpOverride;
      }
      //    tempBoilerSet = op;
      roomtemp_last = roomtemp;
    }
  }

  #ifdef debug
  sprintf(log_chars,"Statusy openth: COHEAT: %s, DHW: %s, automodeCO: %s, temp_NEWS: %f", COHeat?"chodzi":"stoi", String(enableHotWater?"chodzi":"stoi").c_str(), String(automodeCO?"ON":"stoi").c_str(), temp_NEWS);
  log_message(log_chars);
  #endif

  #ifdef debug
  log_message((char*)F("Set statuses from dhwTarget"));
  #endif
  if (status_WaterActive) {histCWUtmp = 0;} //reset to heat longer (to Set temp) if active -on next request
  OpenTherm.setDHWSetpoint(dhwTarget - histCWUtmp);
  #ifdef debug
  log_message((char*)F("Set statuses from op"));
  #endif
  if (status_CHActive) {histCOtmp = 0;} //reset to increase heat to Set temperature if active CO -on next request
  OpenTherm.setBoilerTemperature(op - histCOtmp);

  #ifdef debug
  log_message((char*)F("Set statuses from isFlameOn"));
  #endif
  if (status_flame_prv != status_FlameOn) {
    if (status_FlameOn) {
      start_flame_time = millis();
      start_flame_time_fordisplay = start_flame_time;
    } else {
      start_flame_time = 0;
      start_flame_time_fordisplay = start_flame_time;//After change flame status If flame is on get timer, else reset timer
    }
  }

  unsigned long  response = 0;
  if (OpenTherm.isReady()) {
    #ifdef debug
    log_message((char*)F("OpenTherm make request"));
    #endif
    response = OpenTherm.setBoilerStatus(COHeat, enableHotWater, enableCooling); // enableOutsideTemperatureCompensation

    OpenThermResponseStatus responseStatus = OpenTherm.getLastResponseStatus();
    // LastboilerResponse = F("response");
    // LastboilerResponse += String(response, HEX);
    LastboilerResponse = F("Status ");
    LastboilerResponse += OpenTherm.statusToString(responseStatus);
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

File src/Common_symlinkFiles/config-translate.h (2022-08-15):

#ifdef PL_lang
#define Boiler_And_CO_Temperature "Temperatura Boilera i do CO"
#define Set_Temperature_for_CO_heat "Temperatura do CO USTAW: "
#define Flame_Active_Flame_level "Płomień aktywny. Moc palnika: "
#define Boiler_Active_heat_DHW "Piec w trybie aktywnego podgrzewania CWU wody użytkowej"
#define DHW_HEAT_ON "Podgrzewanie WODY CWU włączone"
#define BOILER_HEAT_ON "Ogrzewanie CO włączone"
#define BOILER_IS_HEATING "Piec w trybie aktywnego grzania CO"
#define DiagMode "Tryb Diagnostyczny"
#define CoolingMode "Tryb Chłodzenia"
#define Second_Engine_Heating_PompActive "Pompa CO pieca węglowego aktywna"
#define Second_Engine_Heating_PompActive_Disable_heat "Pompa CO pieca węglowego aktywna -dezaktywuje grzanie;)"
#define Second_Engine_Heating_Water_PompActive "Pompa Wody pieca węglowego aktywna"
#define Update_web_link "Aktualizacja"
#define Web_Serial "Serial Terminal"
#define Boler_mode "Tryb pracy kotła CO:"
#define Automatic_mode "Automatyczny tryb"
#define DHW_Mode "Tryb pracy CWU:"
#define Heating "Grzanie"
#define Off "Wyłączone"
#define DHW_Temp "Temperatura WODY:"
#define DHW_Temp_Set "Temperatura Wody Docel.: "
#define Room_Temp "Temperatura Pokoju"
#define Room_Temp_Set "Temperatura Pokoju Docel.: "
#define Temp_NEWS "Średnia Temperatura Zewnątrz NEWS:"
#define Temp_BoilerRoom "Temperatura kotłownia"
#define Temp_COHeat "Temperatura CO:"
#define Temp_WaterCOHeat "Temperatura baniak wody:"
#define Pressure "Ciśnienie"
#define Attitude "Wysokość"
#define Attitude_real "Wysokość Real"
#define GAS_CO "Gaz CO"
#define ActualFrom "Aktualne od: "
#define Return_temp "Temperatura Powrotu:"
#define Outside_Cutoff_Below "Temperatura progu grzania CO gdy średnia NEWS: &lt; "
#define msg_Connected "Połączony"
#define msg_disConnected "Rozłączony"
#define Flame_total "Suma zużycia: "
#define Flame_time "Czas pracy płomienia: "
#define t_day "dni"
#define t_hour "godz."
#define t_min "min."
#define t_sek "s."
#define roomname "Pokój"
#define pump_loc "Pompa"
#define water_loc "Woda"
#define CO_heat "CO"
#define Temp_N "Temperatura Północ"
#define Temp_E "Temperatura Wschód"
#define Temp_W "Temperatura Zachód"
#define Temp_S "Temperatura Południe"
#define Temp_T1 "Temperatura dodatkowy"
#define FloorPumpActive " Pompa kondygnacji aktywna..."
#define humidcorstr "Wilgotność"
#define tempcorstr "Temperatura"
#define sMODESTATE "Tryb pracy:"
#define sMODESTATE_HEAT "grzanie"
#define sMODESTATE_COOL "chłodzenie"
#define sMODESTATE_OFF "wyłączone"
// #define min_max_state "min_max_state"
#else
#define Boiler_And_CO_Temperature "Boiler And CO Temperature"
#define Set_Temperature_for_CO_heat "Set Temperature for CO heat: "
#define Flame_Active_Flame_level "Flame_Active. Flame level: "
#define Boiler_Active_heat_DHW "Boiler is in Active heat DHW mode"
#define DHW_HEAT_ON "Domestic Hot Water Heat is Enabled"
#define BOILER_HEAT_ON "Boiler Heat for heating is Enabled"
#define BOILER_IS_HEATING "Boiler is Heating"
#define DiagMode "Diagnostic Mode"
#define CoolingMode "Cooling Mode"
#define Second_Engine_Heating_PompActive_Disable_heat "Second Engine Heating Pomp is Active -Disable boiler heat"
#define Second_Engine_Heating_PompActive "CO wood/coal Heating Pomp is Active"
#define Second_Engine_Heating_Water_PompActive "Second Engine Water Heating Pomp is Active"
#define Update_web_link "Update"
#define Web_Serial "Web_Serial"
#define Boler_mode "Boiler Mode:"
#define Automatic_mode "Automatic mode"
#define DHW_Mode "Domestic HotWater mode:"
#define Heating "Heating"
#define Off "Off"
#define DHW_Temp "Domestic HotWater Temperature:"
#define DHW_Temp_Set " Domestic HotWater Set:"
#define Room_Temp "Current Room Temp"
#define Room_Temp_Set "Room Temperature SET"
#define Temp_NEWS "Averange NEWS Temperature"
#define Temp_BoilerRoom "Boiler-Room Temperature"
#define Temp_COHeat "Temperature CO Heat:"
#define Temp_WaterCOHeat "Temperature Water Heat:"
#define Pressure "Pressure"
#define Attitude "Attitude"
#define Attitude_real "Real Attitude"
#define GAS_CO "Gas CO"
#define ActualFrom "Actual From: "
#define Return_temp "Return Temperature"
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

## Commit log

2022-05-23 corrections change in gui cosmetics Update, Remove ArduinoJson and add my simple implementation to deserialize
    [config-translate.h, config.h, main.cpp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]
2022-05-23 added PBA schematic for wemodD1
    [opentherm-B_Silkscreen.gbr, opentherm-Dolna pasty.gbr, opentherm-Dolna sodermaski.gbr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]
2022-06-12 corrections web dalltermometer link
    [opentherm.kicad_pcb, opentherm.kicad_sch]
2022-07-14 corection automode, almost finalne www, to do: mqtt control correction
    [common_functions.h, config-translate.h, config.h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]
2022-07-20 corrections. add possibility to send commands from serial ;)
    [common_functions.h, config.h, configmqtttopics.h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]
2022-07-20 correction on received mqtt message from HA from automode, correction in flime time calculation
    [main.h]
2022-07-29 missing message on delete config to recreate ;)
    [common_functions.h]
2022-07-30 corrections in read fs
    [common_functions.h, config.h, configmqtttopics.h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]
2022-08-08 slight update mqtt
    [config.cfg]
2022-08-22 correction of OT status message ;)
    [common_functions.h, main.cpp]
2022-08-27 last reset display corr
    [common_functions.h]
